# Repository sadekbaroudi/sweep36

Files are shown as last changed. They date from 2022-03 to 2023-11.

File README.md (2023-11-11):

# Name

sweep36

A 36 key version of the sweep, maintaining the original diodeless pcb.

# Variations

## sweeeeep

why the name sweeeeep? because an elite-c is required to support the extra features, and an elite-c has 5 additional pins... so 5 Es for the 5 extra pins. Yes, it's dumb, I know.

### Descripiton

This is a reversible pcb that is wired only, has per key leds (only on one of the two variations), oled, and choc spacing. In order to continue to support a no diode setup, I added support for the elite-c, and this is now required for the build. You can use alternative elite-c compatible controllers.

### Versions and features

There are 6 versions of this pcb, as found in the pcb/wired-rgb directory:
* choc: No hotswap, 36 keys
* choc-rotated-inner-thumb: No hotswap, 36 keys, rotated inner thumb similar to the corne
* choc-hotswap: Hotswap only, 36 keys
* ks27-choc: Support for both choc and gateron ks-27 switches, no hotswap. Note that ks-27 switches use MX keycaps on a low profile switch. Given it's choc spacing, you will likely need to use custom smaller MX keycaps if using these switches
* choc-evq-inside: No hotswap, 34 key, with an evqwgd001 roller encoder on the inside thumb key
* choc-evq-outside: No hotswap, 34 key, with an evqwgd001 roller encoder on the outside thumb key

## swweeep

So, to keep the silliness going, this is has an extra W for the wireless only, and 3 Es for the 3 extra required pins on the nice!nano.

### Description (and story)

This was created after the sweeeeep as a wireless alternative. Given the nice!nano has two less gpio than the elite-c, had to remove the data pin (and therefore TRRS). So, this is wireless only!

Given it's a wireless only build, it made sense to add nice!view support, given it consumes 1000x less power than the typical OLED. That meant that it would consume one too many gpio. In the spirit of low power consumption, removing per key rgb was a natural decision, leaving it with just enough gpio for this board.

So, backstory aside, the net of it is:
* nice!nano required
* nice!view support
* wireless only (no TRRS)
* JST spaced battery through holes
* on/off switch
* both kailh hotswap and mill max compatible through hole

Special thanks to @jasonhazel for kickstarting the initiative!

### Notes

Regarding the JST footprint, you can solder directly or use jst. If soldering, connect power to the middle hole (with the +) and GND to the -. If using JST, be sure to look at your battery wiring and connect the JST connector such that the power lines up with the middle pin (again, with thhe + on the silkscreen)

It is possible to also produce a PCB baseplate board for the swweeep with a nice silkscreen, the kicad files are [here](https://github.com/sadekbaroudi/sweep36/tree/master/sweeeeep), or if you think the [Great Wave Off Kanagawa](https://en.wikipedia.org/wiki/The_Great_Wave_off_Kanagawa) would make a good silkscreen, the gerbers for that are [here](https://github.com/sadekbaroudi/sweep36/blob/master/swweeep/swweeep-base/gerber/v1.0-kanagawa-gerbers.zip)

## dweeeeep

### Description

This was created after both of the other variations. It was created as an alternative to the sweeeeep. It's a sweeeeep with diodes. I know the principle of the original sweep was to have no diodes. I apologize, this was a special request to allow people to use a pro micro compatible controller, as they're much cheaper.

# Support me!

I have spent a lot of time and money designing prototypes, testing, developing, etc. Any contributions would be greatly appreciated!

If you don't want to, or can't afford to support me, please send me a message to let me know you've built one, along with pictures. Also, feel free to submit a pull request with pictures into this repository. I'd be happy to showcase your build.

Reddit: /u/sadekbaroudi
Discord: sadekbaroudi#1258



# Firmware

## Vial (wired version only)

Special thanks to [Jason Hazel](https://github.com/jasonhazel) for adding vial support. Note that given vial with split code takes up most of the space, there is no support for the OLED or per key RGB. If you want those features, please use QMK below.

https://github.com/sadekbaroudi/vial-qmk/tree/vial/keyboards/fingerpunch/sweeeeep

## QMK (wired version only)

https://github.com/sadekbaroudi/qmk_firmware/tree/master/keyboards/fingerpunch/sweeeeep

## ZMK (wireless version only)

https://github.com/sadekbaroudi/zmk-swweeep

# swweeep v1.3 fix

If you built a swweeep v1.3 or earlier, you will need to connect the battery ground pin to the controller gnd pin, as shown below:

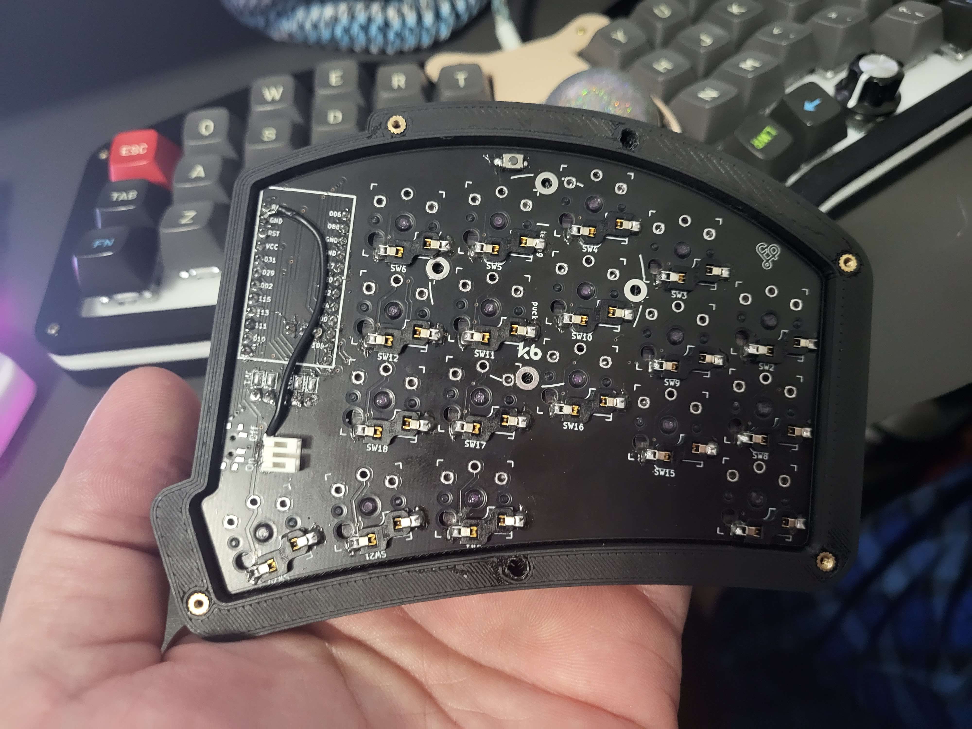
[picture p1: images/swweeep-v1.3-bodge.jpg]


# Pictures

## swweeep with nice!view

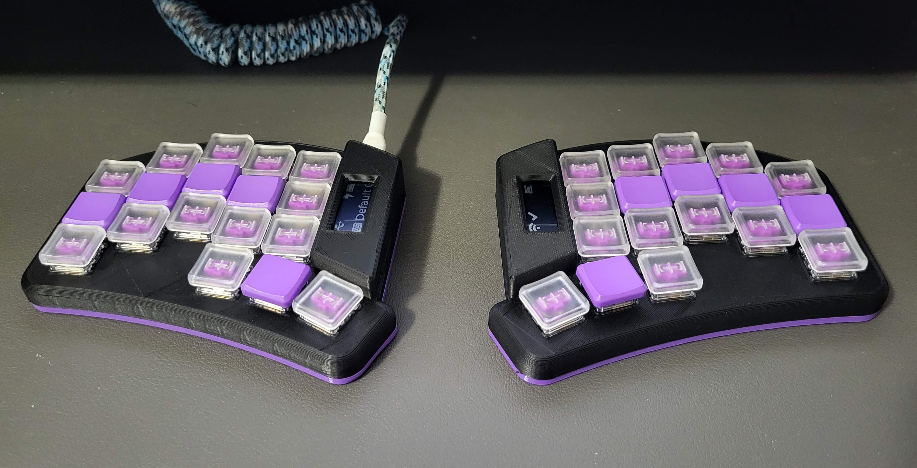
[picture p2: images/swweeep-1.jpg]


## swweeep with the base plate

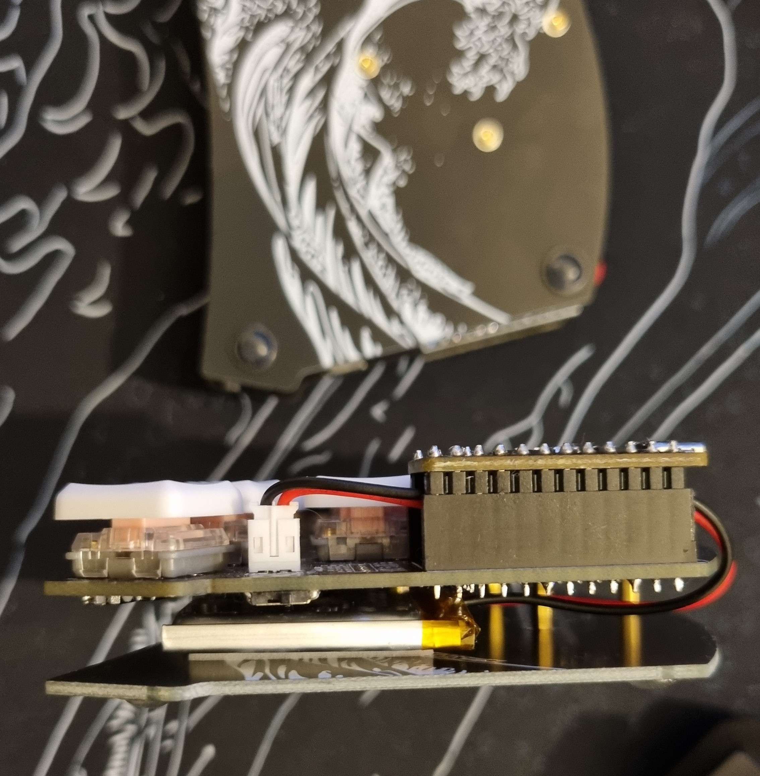
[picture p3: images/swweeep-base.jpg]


## sweeeeep choc

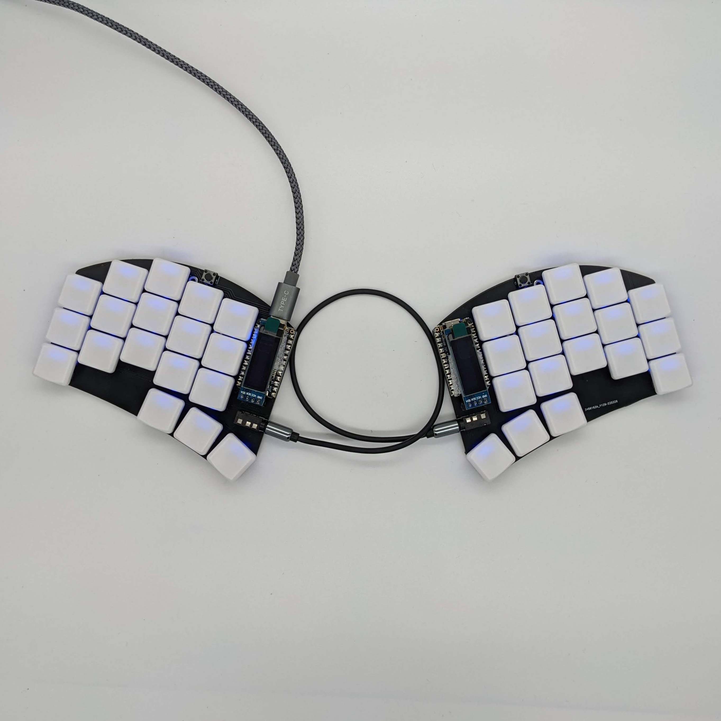
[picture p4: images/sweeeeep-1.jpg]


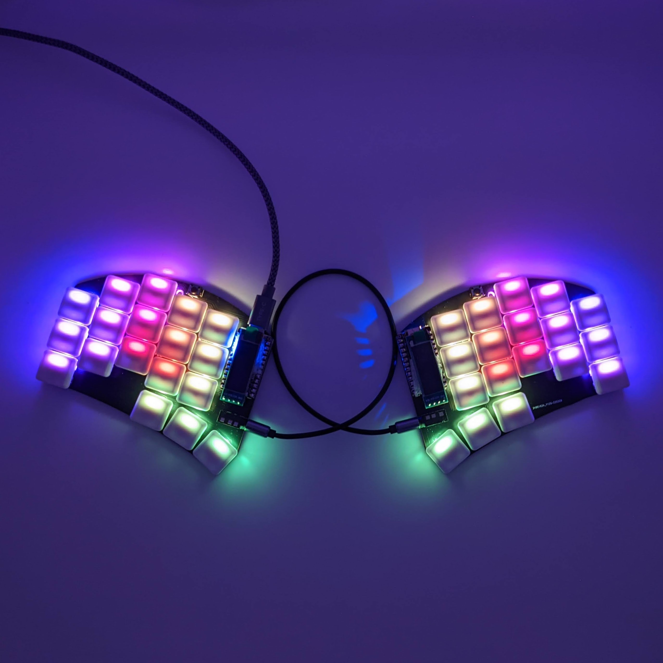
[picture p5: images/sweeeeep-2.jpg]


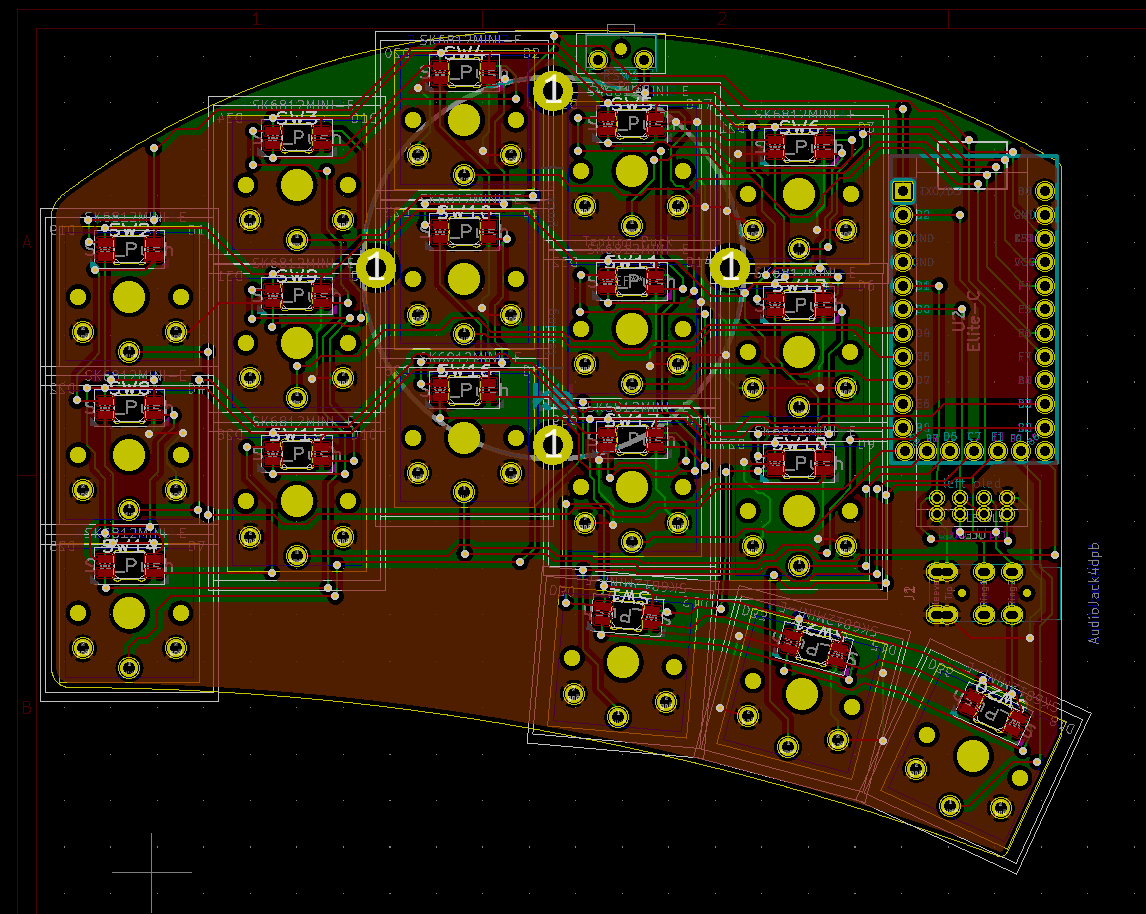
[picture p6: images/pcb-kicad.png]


## sweeeeep evq inside

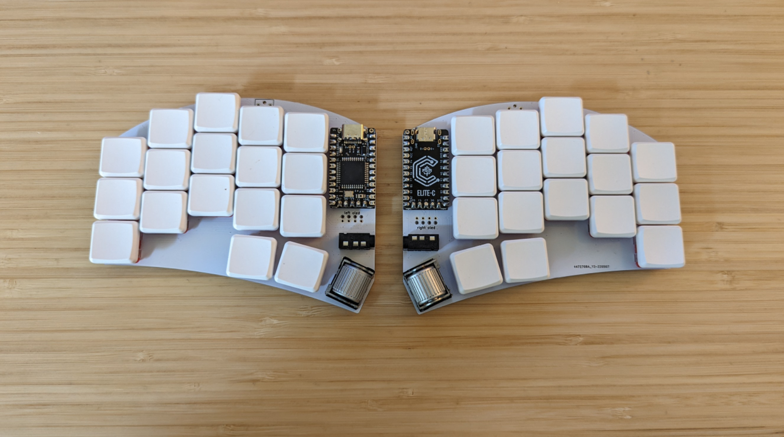
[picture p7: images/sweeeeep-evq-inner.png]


### sweeeeep (choc)
| Front | Back |
| :---: | :---: |
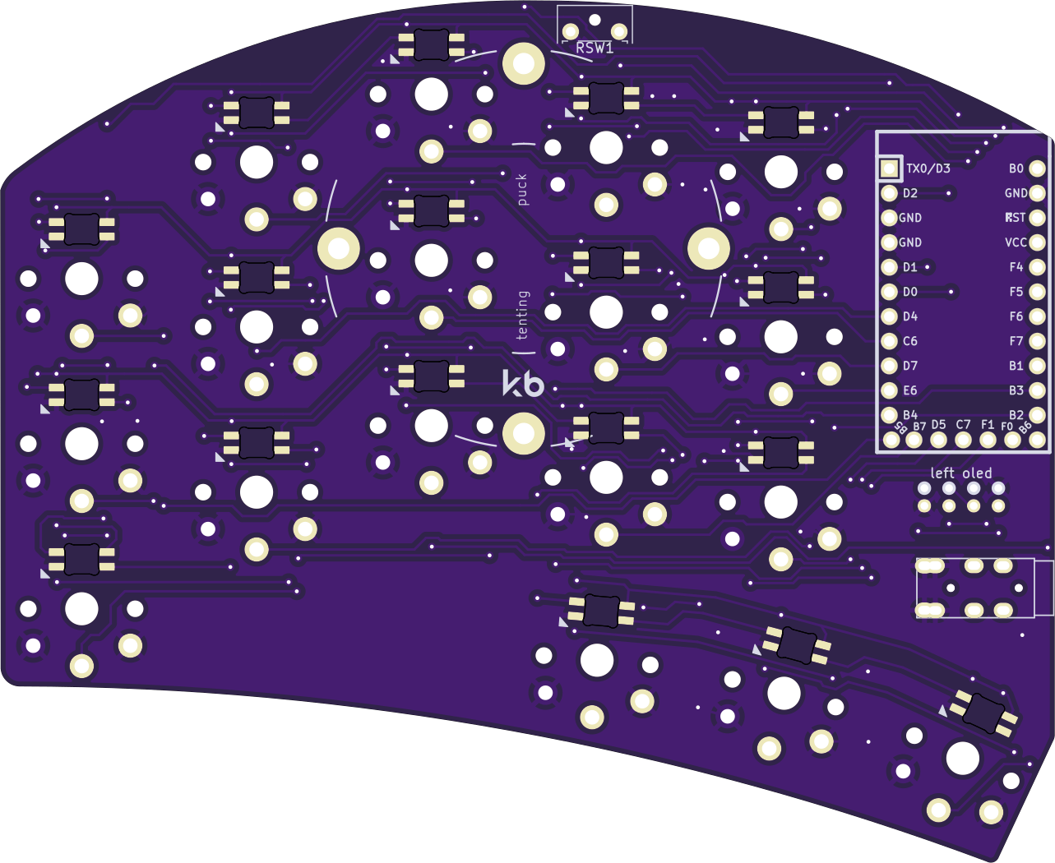
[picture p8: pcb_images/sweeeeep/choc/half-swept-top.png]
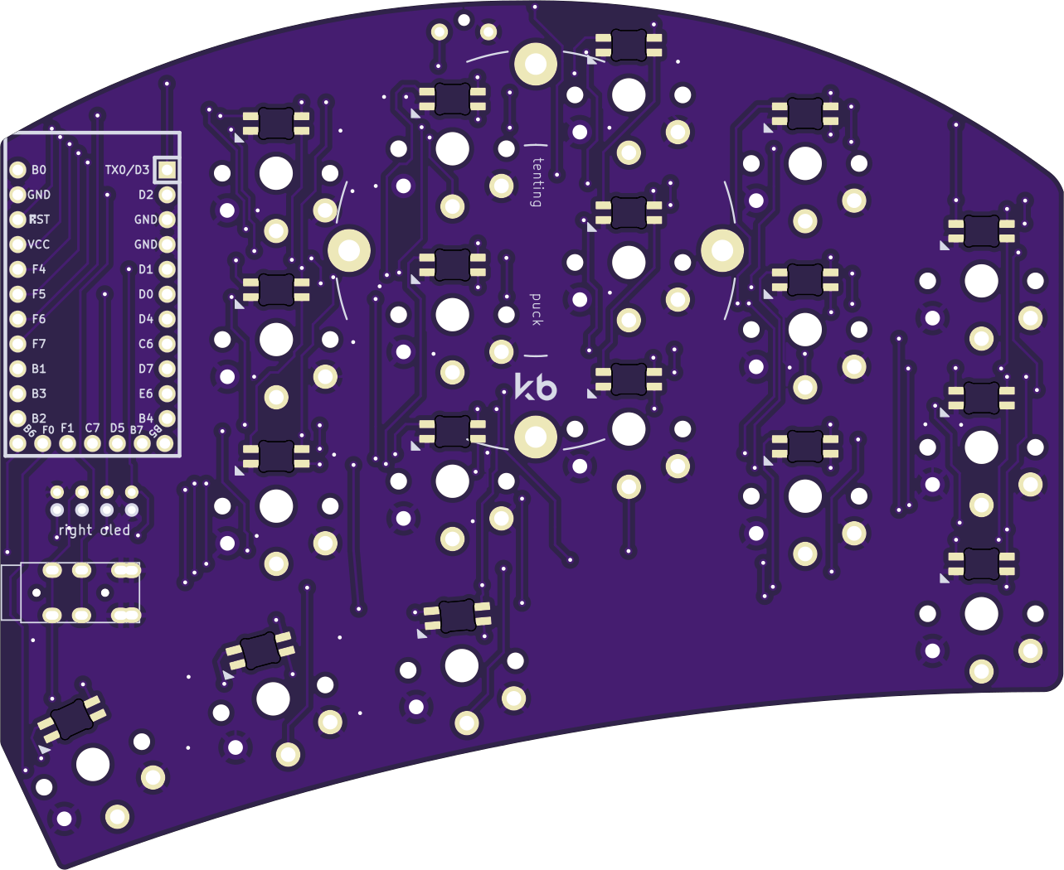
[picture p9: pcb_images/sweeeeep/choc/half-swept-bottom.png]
|  |  |

### sweeeeep (choc-evq-inside)
| Front | Back |
| :---: | :---: |
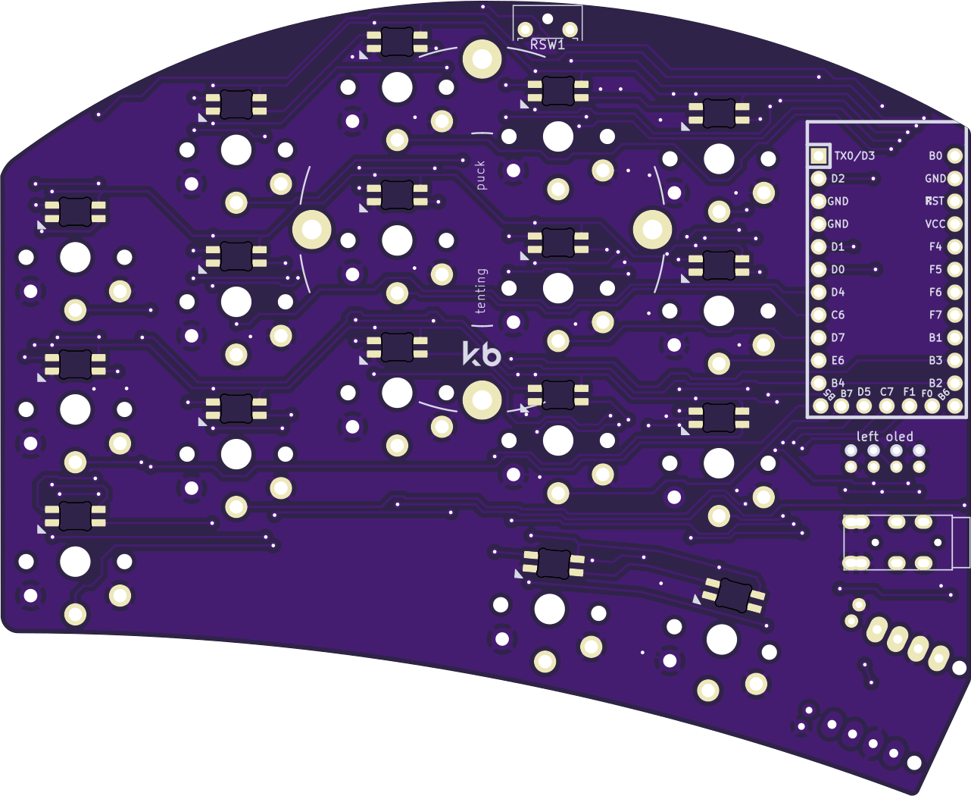
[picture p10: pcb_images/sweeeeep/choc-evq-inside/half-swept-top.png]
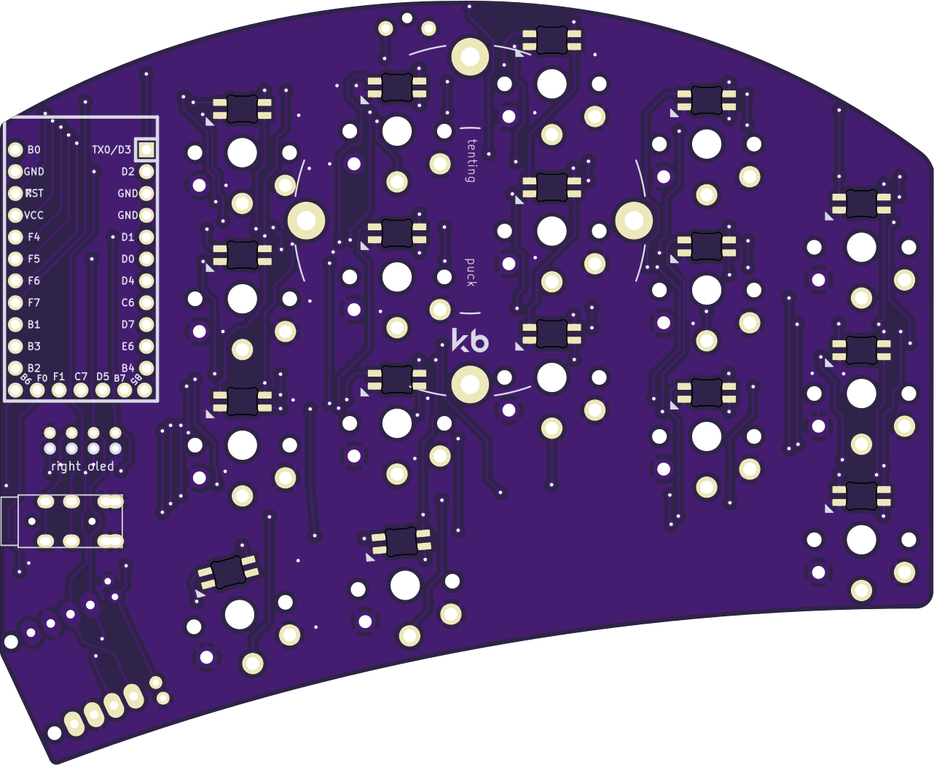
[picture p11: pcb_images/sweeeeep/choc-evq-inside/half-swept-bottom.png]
|  |  |

### sweeeeep (choc-evq-outside)
| Front | Back |
| :---: | :---: |
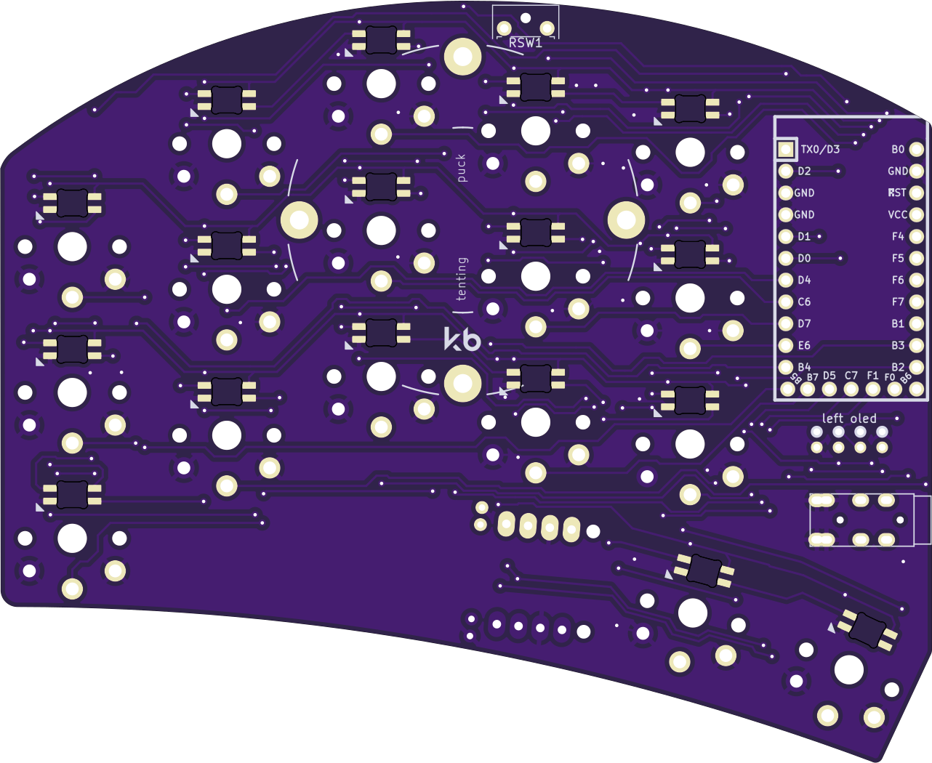
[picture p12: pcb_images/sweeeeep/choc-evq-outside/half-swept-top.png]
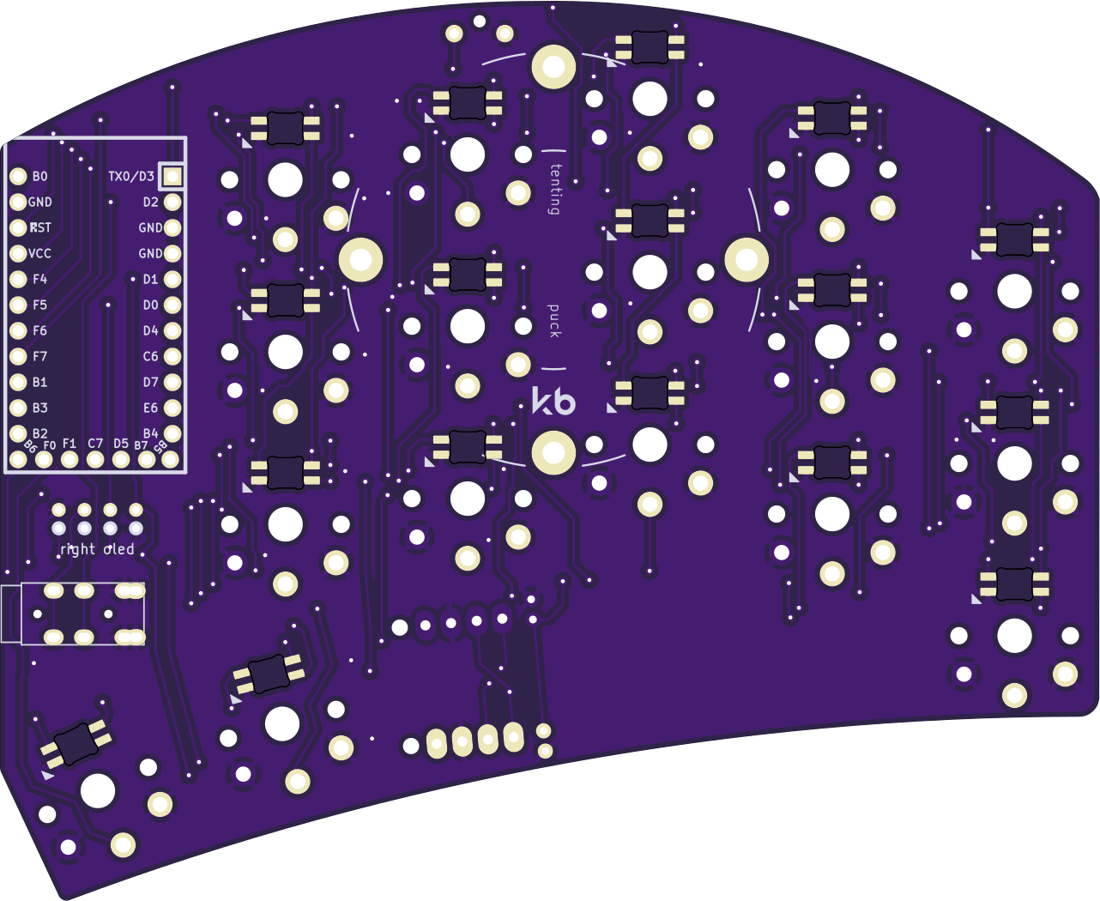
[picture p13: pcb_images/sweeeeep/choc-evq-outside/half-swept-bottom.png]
|  |  |

### sweeeeep (choc-hotswap)
| Front | Back |
| :---: | :---: |
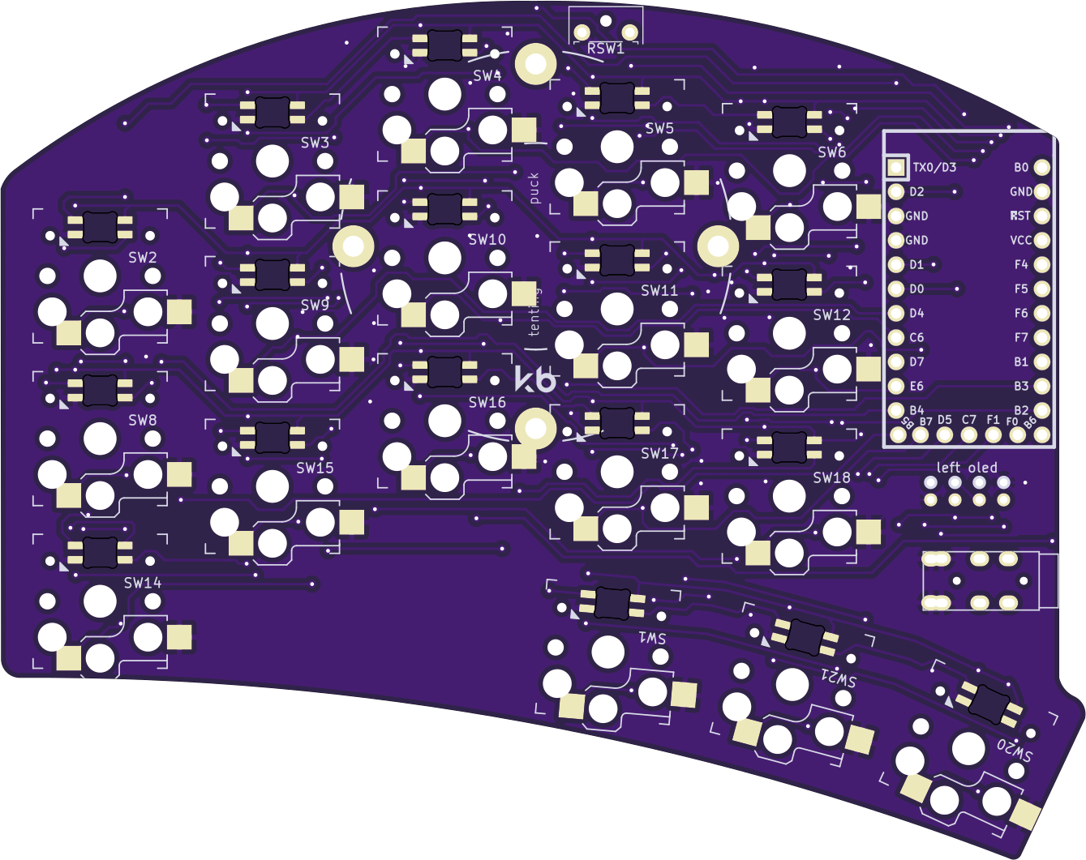
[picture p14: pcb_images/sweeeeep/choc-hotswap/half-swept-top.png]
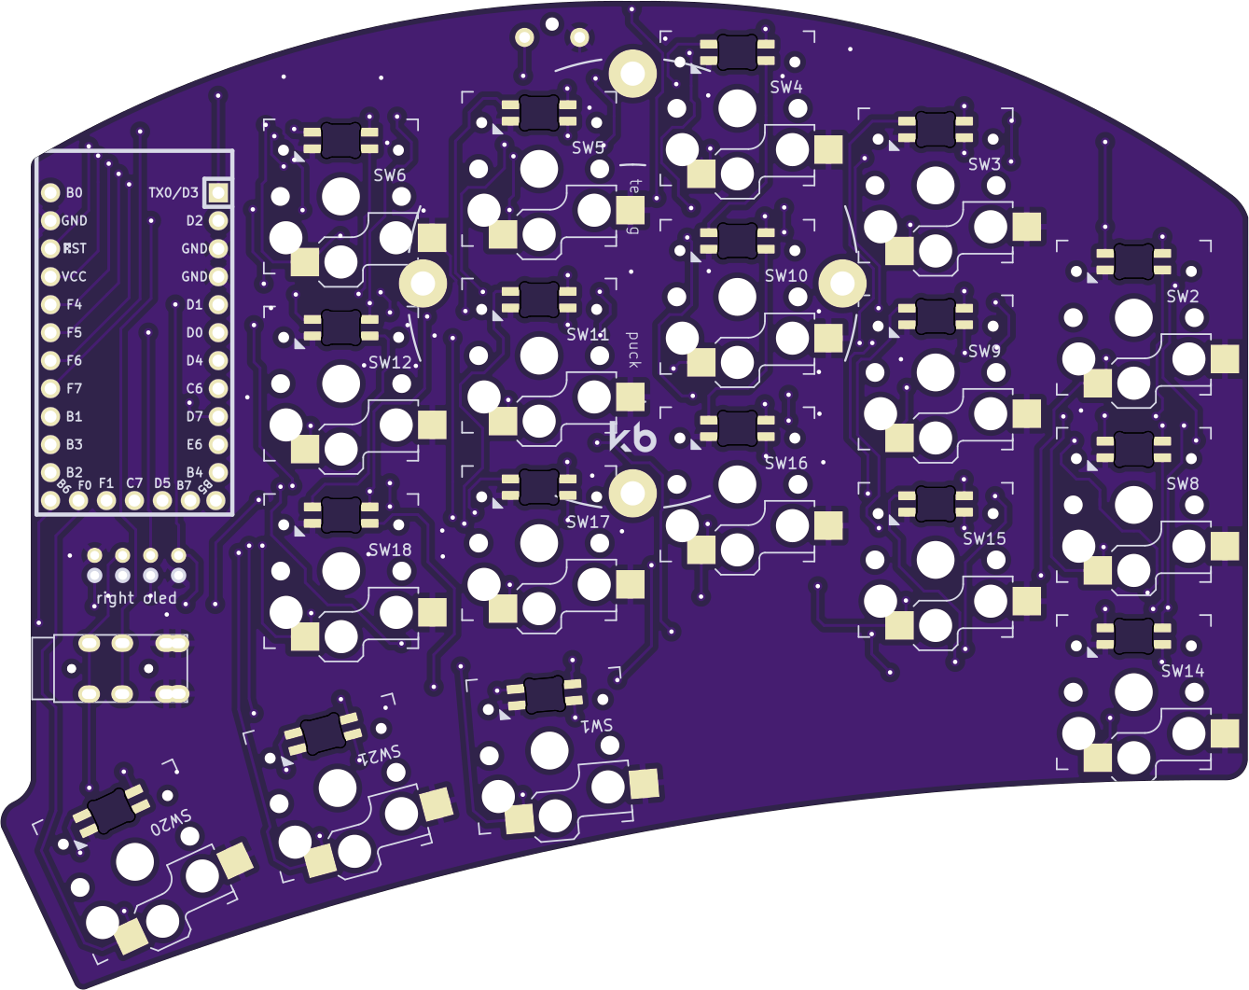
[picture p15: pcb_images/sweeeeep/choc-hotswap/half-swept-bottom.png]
|  |  |

### sweeeeep (choc-rotated-inner-thumb)
| Front | Back |
| :---: | :---: |
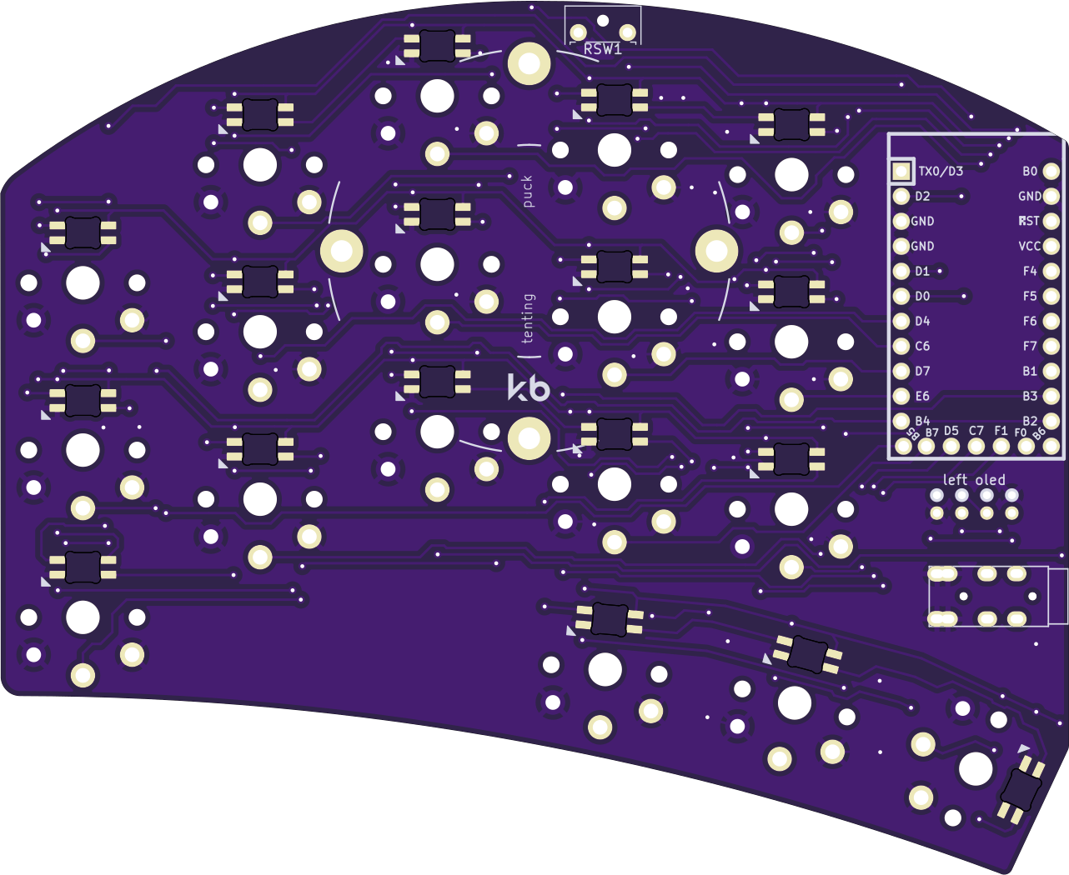
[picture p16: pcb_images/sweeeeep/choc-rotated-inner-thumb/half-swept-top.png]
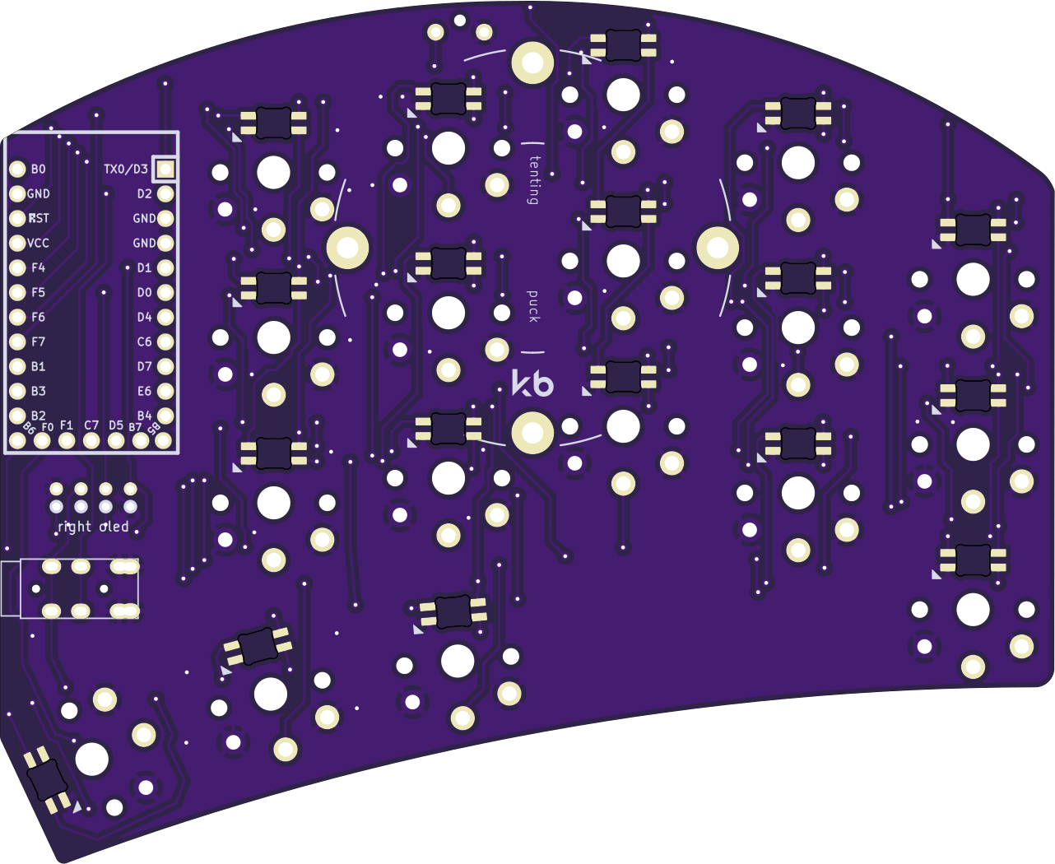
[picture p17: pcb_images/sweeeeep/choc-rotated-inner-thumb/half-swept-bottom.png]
|  |  |

### sweeeeep (ks27-choc)
| Front | Back |
| :---: | :---: |
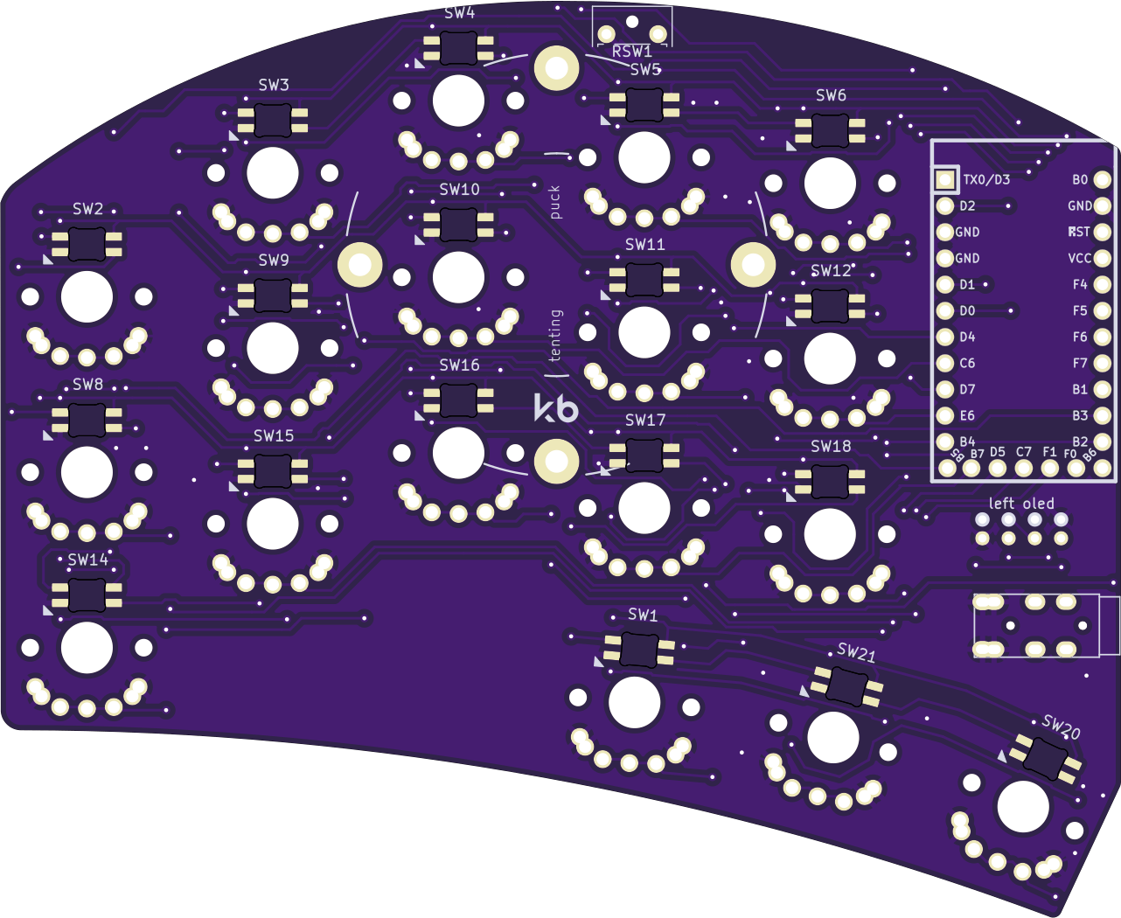
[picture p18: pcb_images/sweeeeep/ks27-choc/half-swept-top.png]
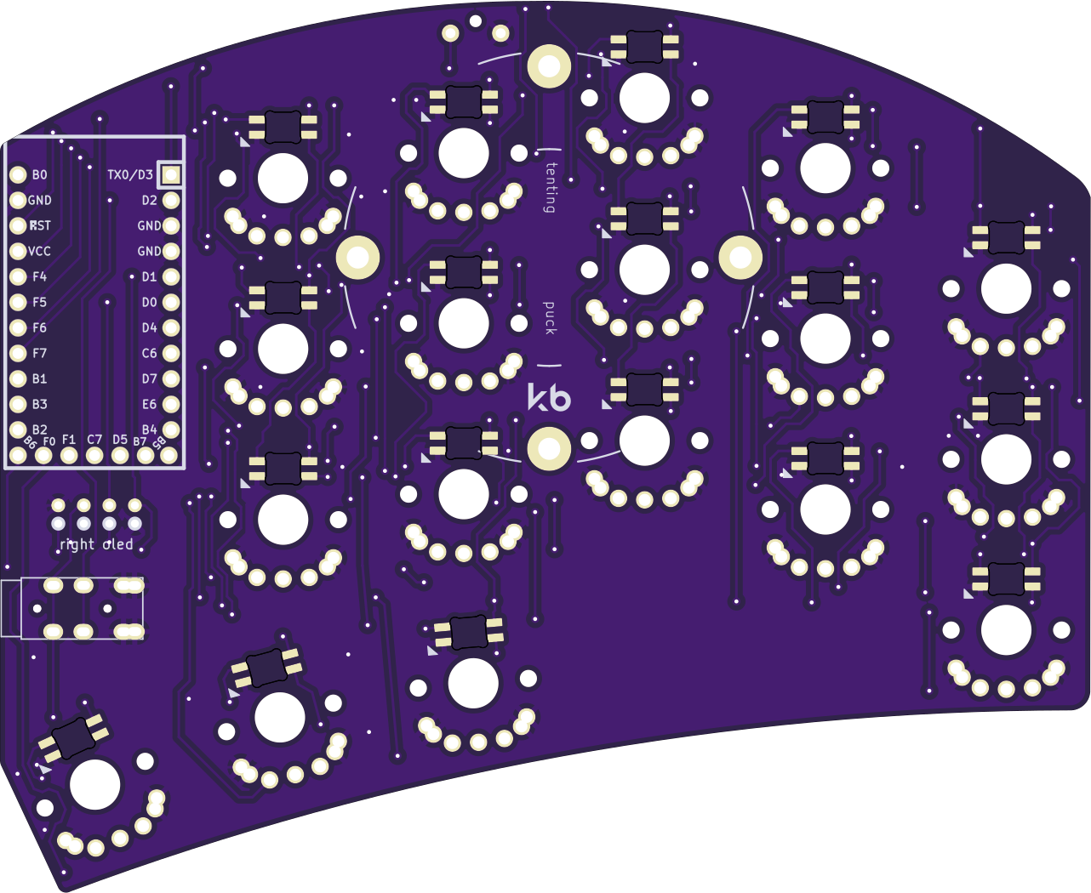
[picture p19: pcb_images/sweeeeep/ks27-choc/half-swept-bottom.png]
|  |  |

### swweeep (choc-hotswap-optional)
| Front | Back |
| :---: | :---: |
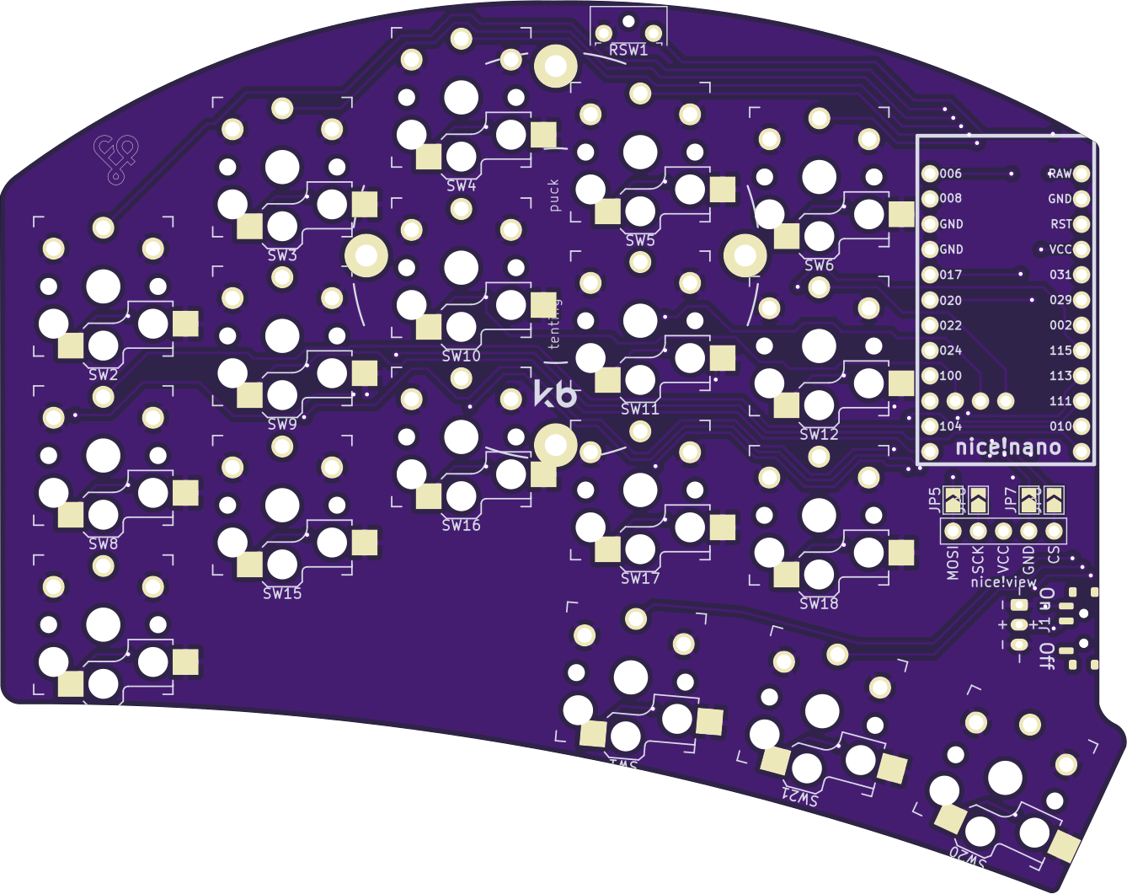
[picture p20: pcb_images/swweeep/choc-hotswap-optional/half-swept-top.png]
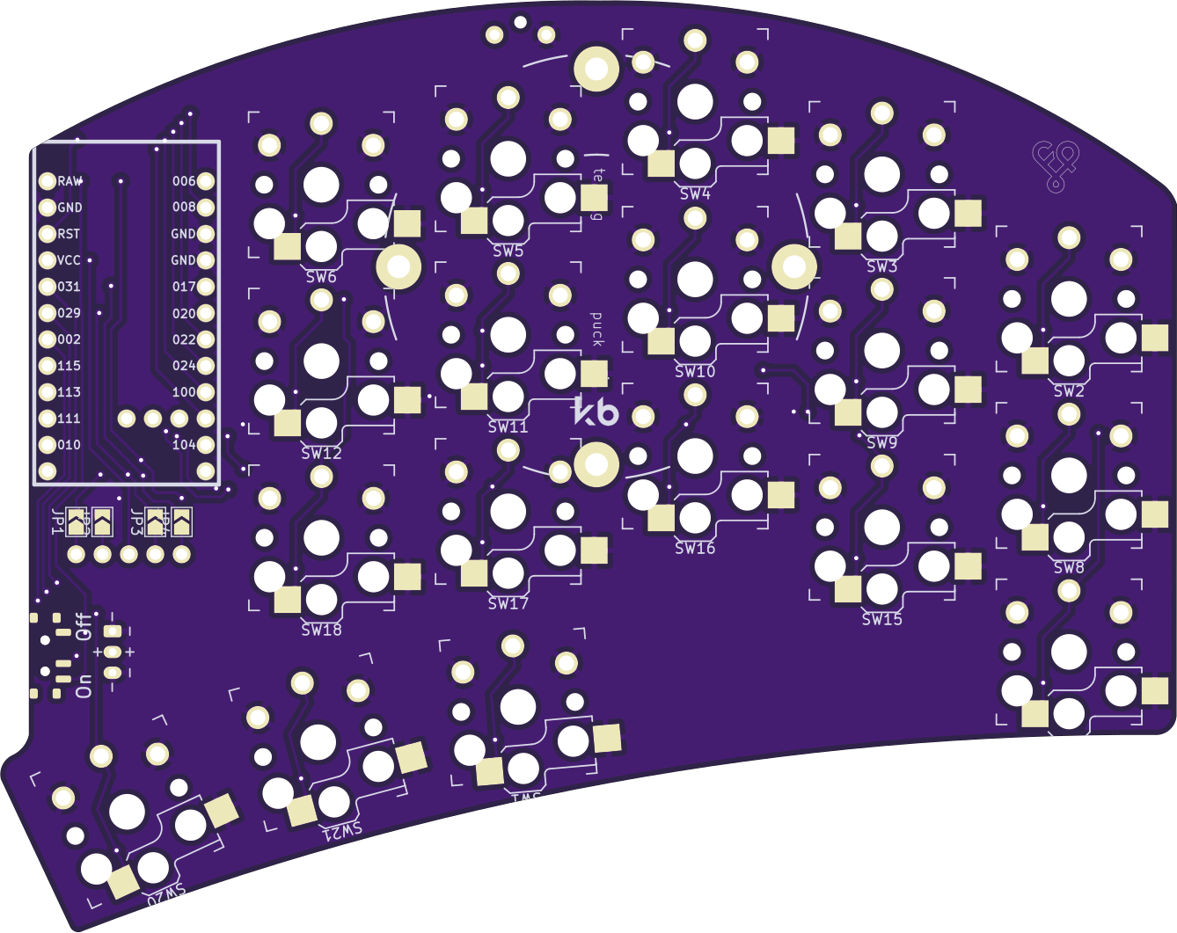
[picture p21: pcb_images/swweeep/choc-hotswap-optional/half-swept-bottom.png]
|  |  |

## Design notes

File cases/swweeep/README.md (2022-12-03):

# swweeep case

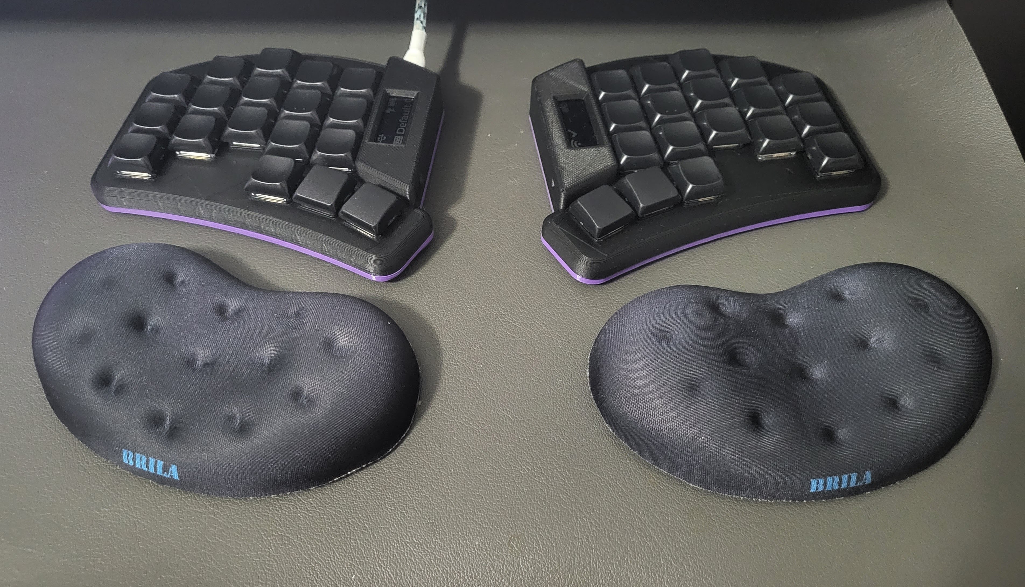
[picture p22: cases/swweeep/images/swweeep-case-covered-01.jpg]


## Required parts

* 2x body
* 2x bottom plate
* On off switch extension (optional)
* 8-12x M2 heat set inserts, 4mm in length
* 8-12x M2 screws, 4-6mm in length (5mm is best)

`swweeep-on-off-extension-small`, `swweeep-on-off-extension-medium`, and `swweeep-on-off-extension-large`

## Bodies

### swweeep-body-open-left

This is an uncovered case, which means the controller is exposed. Not recommended if using the nice!view, but fine otherwise

### swweeep-body-covered-left

Covered controller, to be used with a nice!view

### swweeep-body-covered-widecover-left

Covered controller, to be used with nice!view. This provides enough room on the side of the controller to store a 110 mah battery. Note that this leaves the on/off switch a bit from from the opening on the inside, so you'll need more precision with tweezers or a paper clip to turn it on and off.

However, given you can store the battery on top, you can use the thin bottom bottom plate with this ( `swweeep-bot-widecover-left` )

## Bottom Plates

### swweeep-bot-left

This is a thin bottom plate, intended to be used with `swweeep-body-covered-left` or `swweeep-body-open-left`. Only use this plate if you have a 3mm thick battery and you are not using a JST connector. Otherwise, please use the `swweeep-bot-3mm-left` plate.

### swweeep-bot-3mm-left

This is a thin bottom plate, intended to be used with `swweeep-body-covered-left` or `swweeep-body-open-left`. As mentioned above, made to give a little extra room for a 4mm-4.5mm thick battery and/or a JST connector.

### swweeep-bot-widecover-left

This is a thin bottom plate, intended to be used with `swweeep-body-covered-widecover-left`. Given you are using this case to store the battery on the side of the controller, this is the recommended bottom plate.

### swweeep-bot-widecover-3mm-left

This is a thin bottom plate, intended to be used with `swweeep-body-covered-widecover-left`. I added this for good consistency, but it's unlikely you'd use this one. The only reason to use this bottom plate is that you are using the `swweeep-body-covered-widecover-left` body, not putting the battery next to the controller, and you have a 4mm thick battery or are using a JST connector.

### swweeep-bot-10deg-battery-small

This is a 10 degree tented bottom plate, intended to be used with `swweeep-body-covered-left` or `swweeep-body-open-left`. There is a small battery compartment in the tent to put your battery. Fits a 4mm thick 110 mah battery, up to 12mm x 33mm. Note that if you are using a JST connector, you should use the `swweeep-bot-10deg-battery-large` bottom plate. The positioning of the hole for this one is a bit off to the left, and the JST requires more space between the PCB and the plate.

### swweeep-bot-10deg-battery-large

This is a 10 degree tented bottom plate, intended to be used with `swweeep-body-covered-left` or `swweeep-body-open-left`. There is a large battery compartment in the tent to put your battery. Fits a battery up to 30mm x 52mm x 8mm

### swweeep-bot-18deg-18650

This is a 18 degree tented bottom plate, intended to be used with `swweeep-body-covered-left` or `swweeep-body-open-left`. Run the wires through the small holes in the bottom plate and solder to the pcb. Make sure the wires are long enough that you can safely take off the bottom plate without ripping the wires out of the through holes.

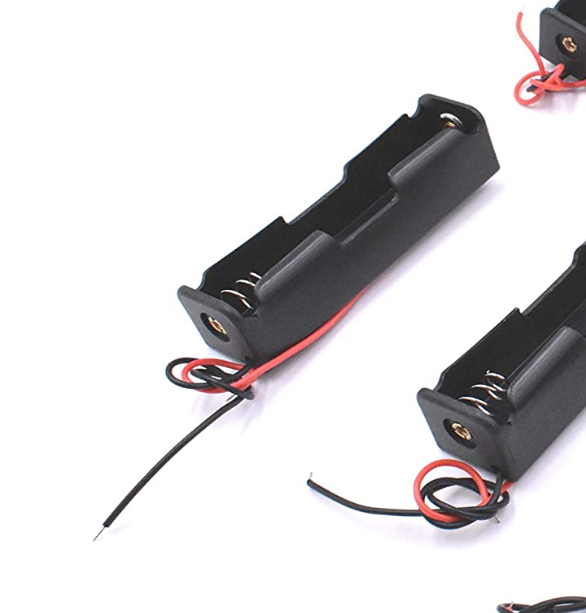
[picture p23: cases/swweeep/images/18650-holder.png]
18650-holder


## On Off Switch Extension

NOTE: This is only intended to be used with swweeep-v1.4 or prior, as I have changed the on/off switch. If you prefer the smaller switch with this switch extension, please feel free to fab v1.4. If you want the larger on/off switch, use v1.5. Please see the releases tab in the github repo to select which you want to use.

This is a cover for the on off switch. It should be placed into the hole for the on off switch before putting the pcb into the case. There are three versions of this, since different printers can generate slightly different results, especially at this scale. Please experiment with all of them until you find one that works.

(Special thanks to @kyek for the idea to do this)

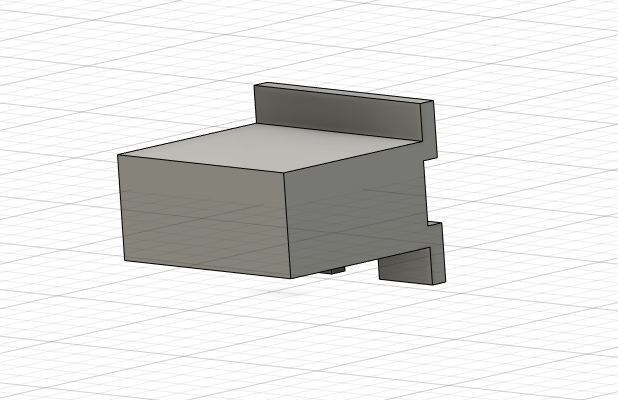
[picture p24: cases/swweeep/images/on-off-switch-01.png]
on-off-switch-01

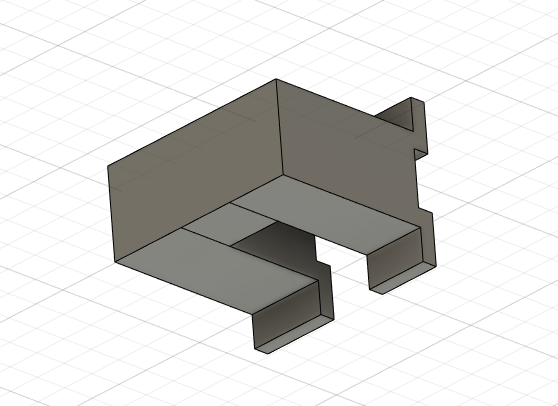
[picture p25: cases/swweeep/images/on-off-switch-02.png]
on-off-switch-02

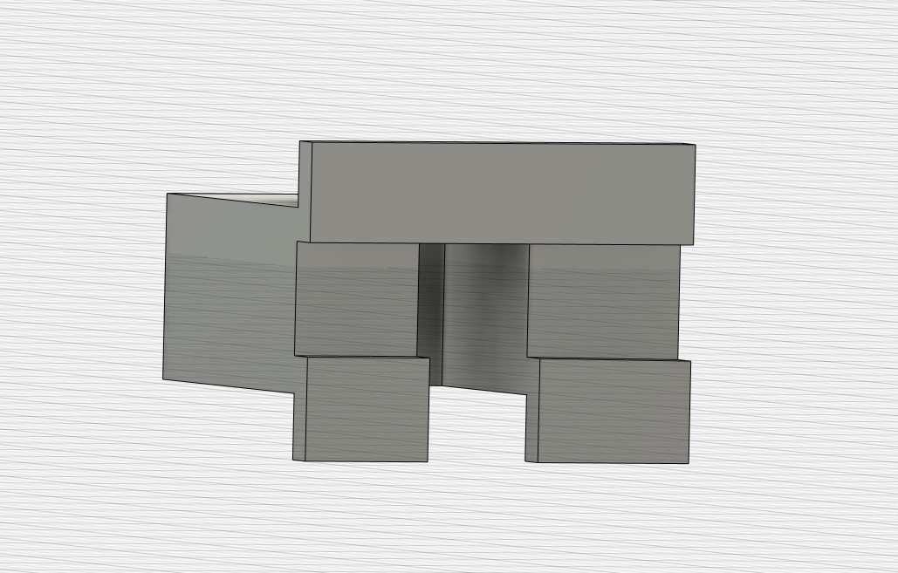
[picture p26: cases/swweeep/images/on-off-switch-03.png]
on-off-switch-03

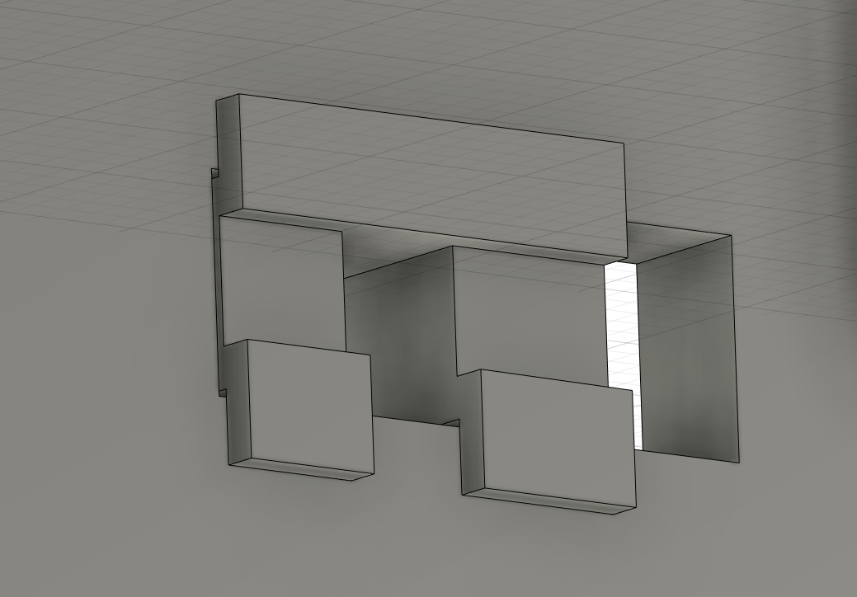
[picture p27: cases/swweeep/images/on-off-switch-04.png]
on-off-switch-04

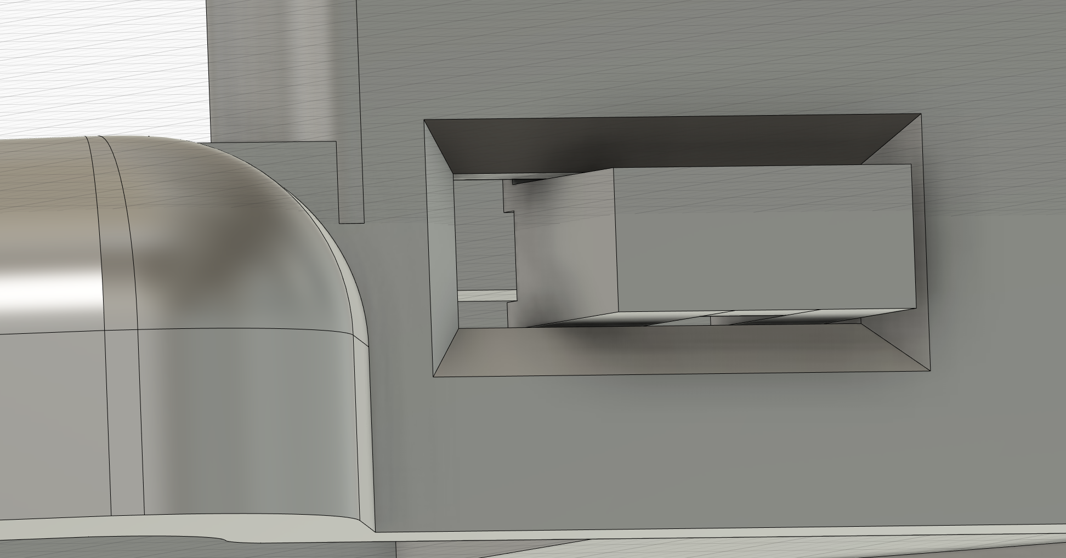
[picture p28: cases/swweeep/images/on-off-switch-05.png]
on-off-switch-05


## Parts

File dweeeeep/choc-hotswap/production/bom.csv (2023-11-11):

Designator | Footprint | Quantity | Value | LCSC Part #
D1, D10, D11, D12, D13, D14, D15, D16, D17, D18, D19, D2, D20, D21, D22, D23, D24, D25, D26, D27, D28, D29, D3, D30, D31, D32, D33, D34, D35, D36, D4, D5, D6, D7, D8, D9 | MX_SK6812MINI-E_REV | 36 | SK6812MINI-E
D37, D38, D39, D40, D41, D42, D43, D44, D45, D46, D47, D48, D49, D50, D51, D52, D53, D54, D55, D56, D57, D58, D59, D60, D61, D62, D63, D64, D65, D66, D67, D68, D69, D70, D71, D72 | D_SOD-123 | 36 | 1N4148W | C727110
J1, J2 | TRRS-PJ-320A | 2 | AudioJack4dpb
OL1, OL2 | OLED_v2 | 2 | OLED
RSW1 | SW_Tactile_SPST_Angled_MJTP1117-no-mount | 1 | SW_Push
SW1, SW10, SW11, SW12, SW14, SW15, SW16, SW17, SW18, SW2, SW20, SW21, SW3, SW4, SW5, SW6, SW8, SW9 | Kailh_socket_PG1350_reversible | 18 | SW_Push
U2 | Elite-C | 1 | Elite-C

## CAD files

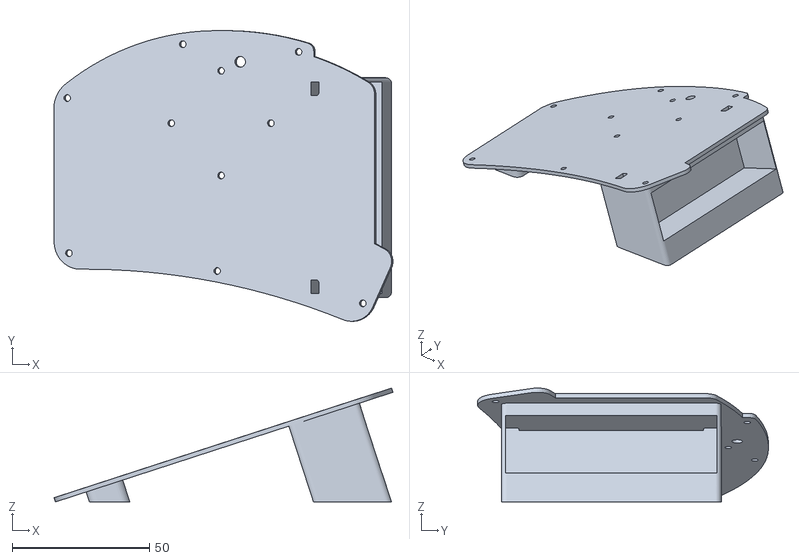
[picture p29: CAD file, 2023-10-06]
cases/swweeep/swweeep-bot-18deg-with-tenting-puck-18650.stl
123.3 x 105.7 x 41.4

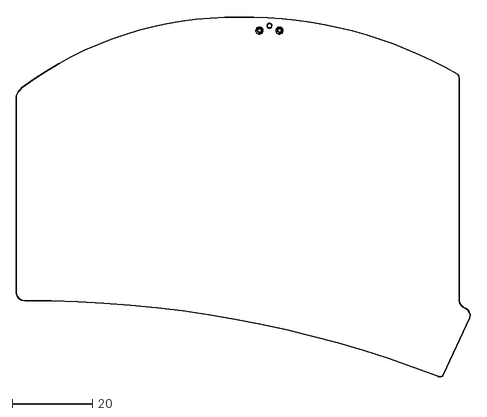
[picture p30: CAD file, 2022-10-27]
swweeep/choc-hotswap-optional/svgs/reset-switch.dxf
113.5 x 90.1

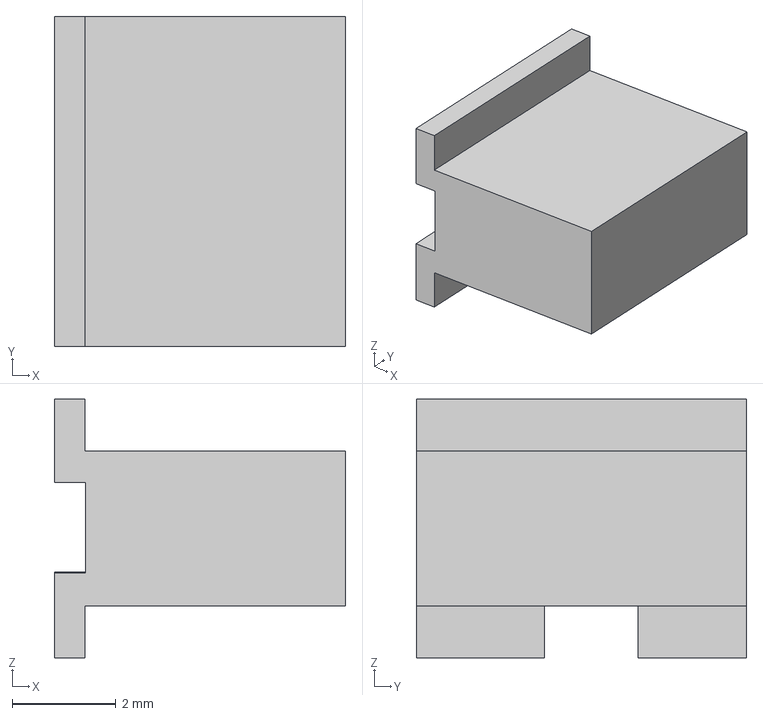
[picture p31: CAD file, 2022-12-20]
cases/swweeep/swweeep-on-off-extension.step
5.60 x 6.36 x 4.98 mm

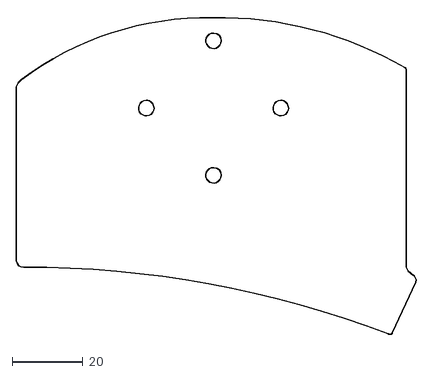
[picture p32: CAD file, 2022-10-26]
swweeep/choc-hotswap-optional/svgs/tenting-puck-placement.dxf
113.5 x 90.1

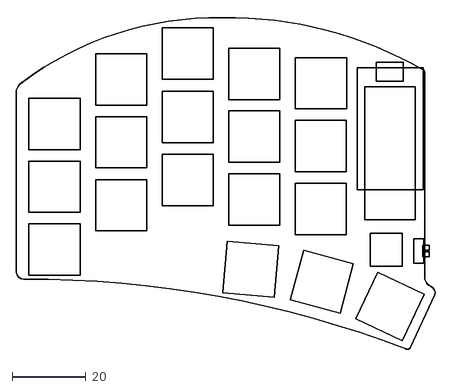
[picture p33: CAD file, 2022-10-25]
swweeep/choc-hotswap-optional/svgs/half-swept-brd.dxf
113.5 x 90.1

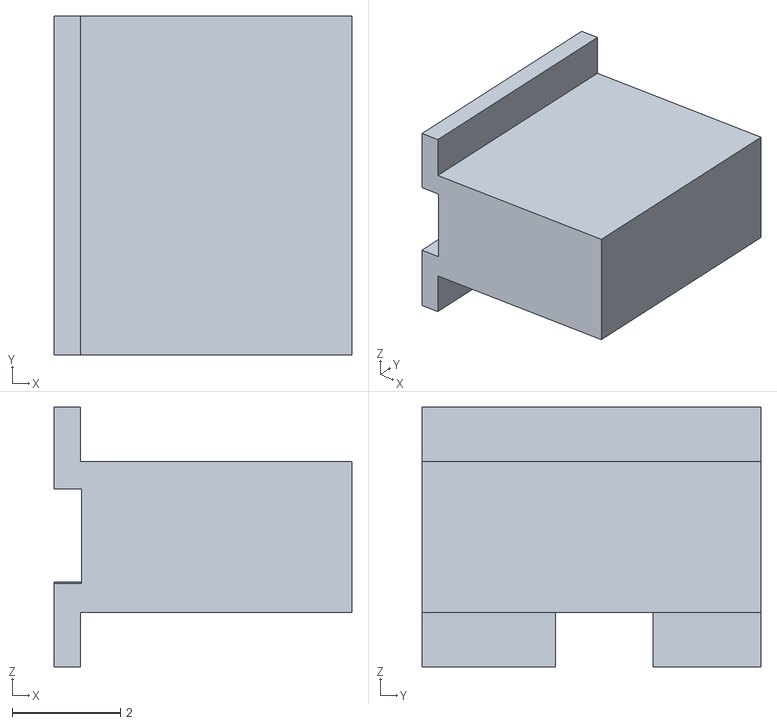
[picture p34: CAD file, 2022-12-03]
cases/swweeep/swweeep-on-off-extension-medium.stl
5.50 x 6.27 x 4.80

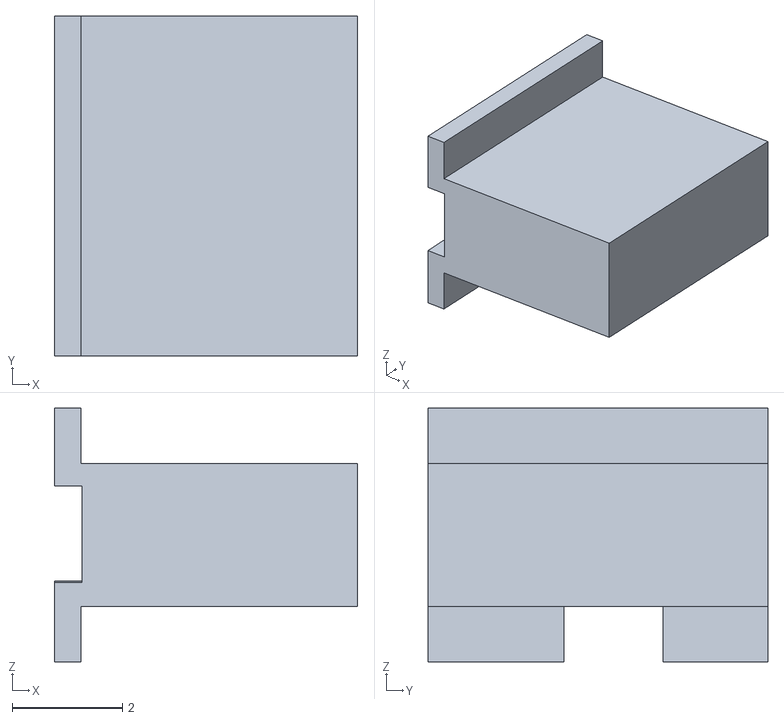
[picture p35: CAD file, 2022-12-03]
cases/swweeep/swweeep-on-off-extension-small.stl
5.50 x 6.17 x 4.60

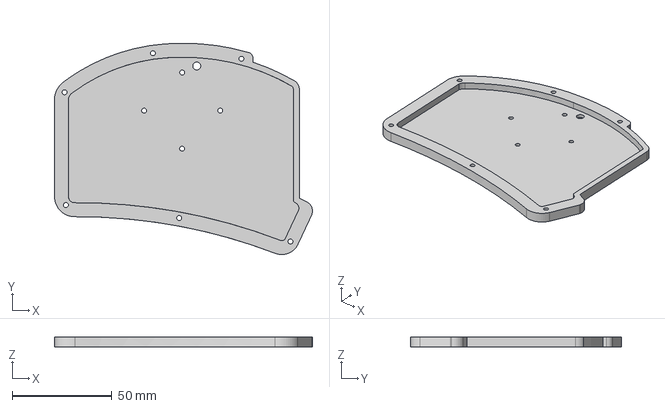
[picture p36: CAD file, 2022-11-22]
cases/swweeep/swweeep-bot-5mm-left.step
129.1 x 105.7 x 5.00 mm

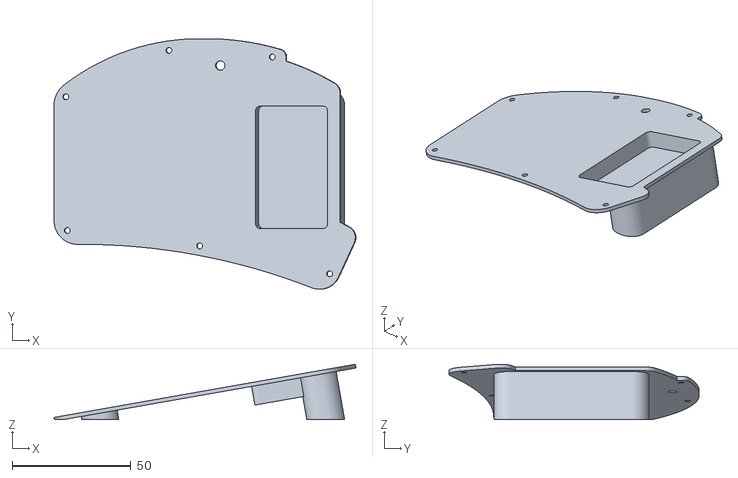
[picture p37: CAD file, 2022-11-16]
cases/swweeep/swweeep-bot-10deg-battery-large.stl
127.4 x 105.7 x 23.4

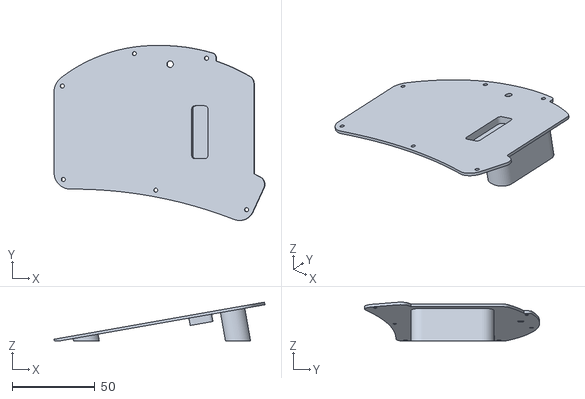
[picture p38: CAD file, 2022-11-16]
cases/swweeep/swweeep-bot-10deg-battery-small.stl
127.4 x 105.7 x 23.4

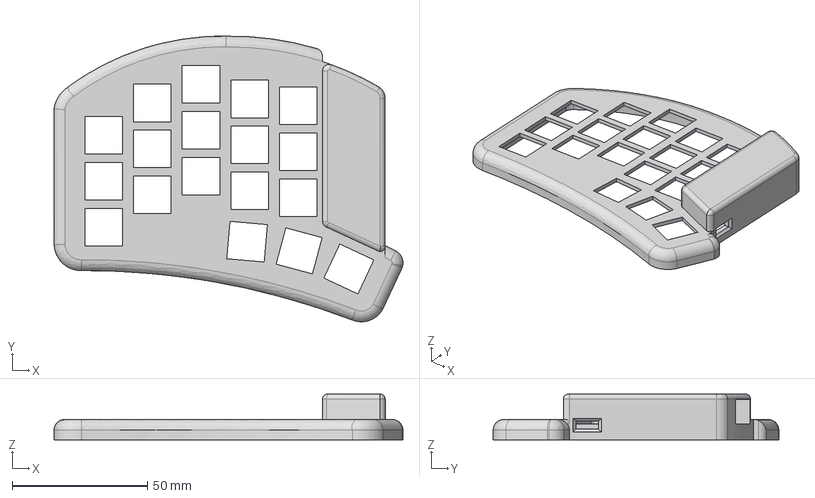
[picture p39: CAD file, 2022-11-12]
cases/swweeep/swweeep-body-covered-noNiceView-left v1.step
129.1 x 105.7 x 17.0 mm

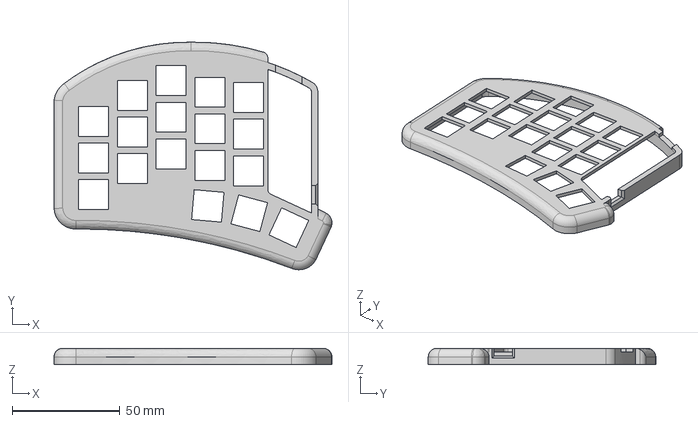
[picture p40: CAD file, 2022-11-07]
cases/swweeep/swweeep-body-open-left.step
129.1 x 105.7 x 7.60 mm

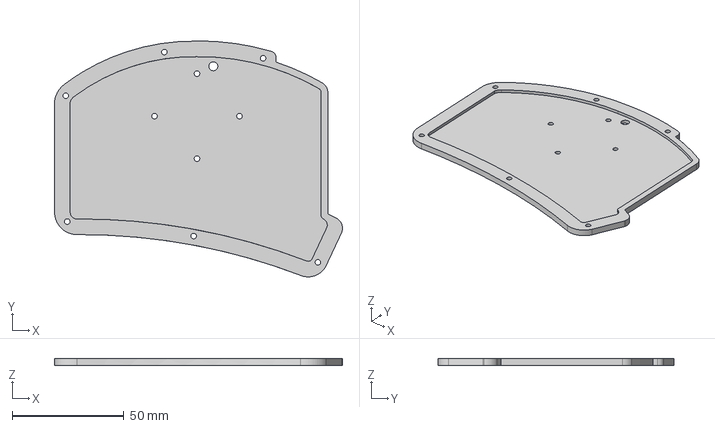
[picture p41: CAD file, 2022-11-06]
cases/swweeep/swweeep-bot-3mm-left.step
129.1 x 105.7 x 3.00 mm

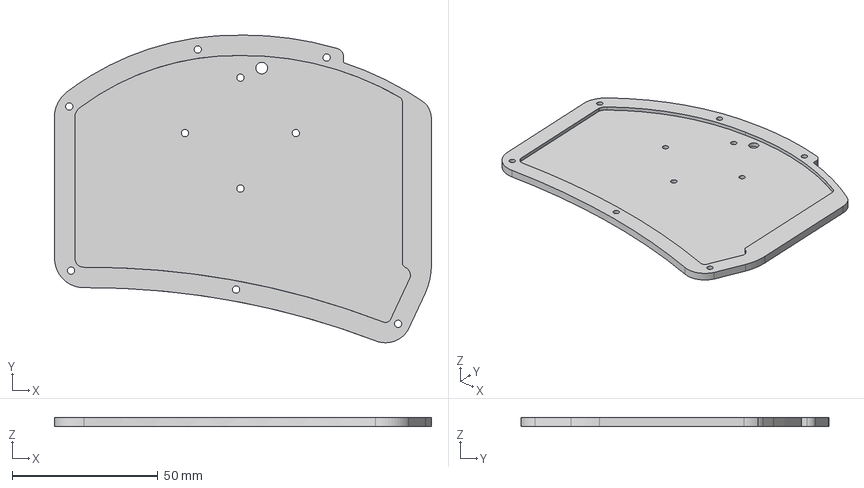
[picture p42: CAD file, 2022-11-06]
cases/swweeep/swweeep-bot-widecover-3mm-left.step
129.6 x 105.7 x 3.00 mm

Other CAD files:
cases/swweeep/swweeep-on-off-extension-large.stl
cases/swweeep/swweeep-bot-18deg-18650.stl
cases/swweeep/swweeep-body-covered-widecover-left.step
cases/swweeep/swweeep-body-covered-left.step
cases/swweeep/swweeep-body-covered-left.stl
cases/swweeep/swweeep-body-covered-noNiceView-left v1.stl
cases/swweeep/swweeep-body-covered-widecover-left.stl
cases/swweeep/swweeep-body-open-left.stl
cases/swweeep/swweeep-bot-3mm-left.stl
cases/swweeep/swweeep-bot-5mm-left.stl
cases/swweeep/swweeep-bot-left.step
cases/swweeep/swweeep-bot-left.stl
cases/swweeep/swweeep-bot-widecover-3mm-left.stl
cases/swweeep/swweeep-bot-widecover-left.step
cases/swweeep/swweeep-bot-widecover-left.stl

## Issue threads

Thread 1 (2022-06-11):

Questions

MisanthropicBit, 2022-06-11:
Thanks for making this keyboard. It is exactly what I've been looking for since I'm already a fan of the ferris sweep (and built one) but wanted 36 keys instead 🙂 This would be my second build though so I'm not terribly experienced and have some questions:

1. What kind of choc semi-transparent keycaps did you use in the pictures? I haven't been able to find something similar in Europe.
2. Can I reuse the same PCB order settings as used in [this Sweep build guide](https://youtu.be/fBPu7AyDtkM?t=21)?
3. What type of hotswaps does the choc-hotswap support? Only [kailh](https://splitkb.com/collections/keyboard-parts/products/kailh-hotswap-sockets), [mill max](https://splitkb.com/collections/keyboard-parts/products/mill-max-hot-swap-sockets), or both?
4. Which LEDs/OLEDs are supported? Can I use these types of [LEDs](https://splitkb.com/collections/keyboard-parts/products/ws2812b-rgb-led?_pos=3&_fid=93ae17f0e&_ss=c) and these [OLED displays](https://splitkb.com/products/oled-display?_pos=1&_sid=3e53e0ada&_ss=r)?

sadekbaroudi, 2022-06-12:
Hi, I'm glad you like it!
1) https://splitkb.com/products/moergo-mcc-profile-1u-keycap
2) Yes!
3) Depends on the version you order... the choc pcb doesn't support hotswap at all. The hotswap version uses kailh
4) You'll need this model of OLED ( https://protosupplies.com/product/oled-0-91-128x32-i2c-white-display/ ) and SK6812 mini-e per key rgb leds

MisanthropicBit, 2022-06-14:
Hey! Thanks for getting back to me.

1. Perfect! Thanks :)
2. Awesome!
3. I plan on ordering the choc-hotswap (if that's what you mean by version) so that should be fine.
4. The OLED screen I linked appears to be the same one, but the LEDs I linked are called SK6812MINI (without the `-e`) so I'm guessing them won't work?

sadekbaroudi, 2022-06-14:
1) No problem! :)
2) N/A
3) Perfect
4) Yeah, they definitely won't work. You need the `-e` as they have a different footprint.

Closed 2022-06-15.

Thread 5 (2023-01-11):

Oled Question

lachlanderrick, 2023-01-11:
Hi mate,

Keyboard looks sweeeeet!

Had a question about oleds. If using [this model](https://protosupplies.com/product/oled-0-91-128x32-i2c-white-display/) that you linked in another isue, are resistors required? I can't see spots for them on the pcb but thought I'd check.

As a related question, what part would you need for socketing the oled? Something like [this](https://kriscables.com/product/oled-hotswap-socket/)? Are there any height requirements for the oled socket?

Cheers!

kriscables, 2023-01-12:
@lachlanderrick from what i checked, i think resistors are not needed, but someone who is more into it could double confirm.

What you linked for socketing Oled is appropriate to use. The height i recommend is the 5mm one, but the 8mm is also possible to use if for some reason you need your oled to stay higher. Also i suggest to use some Dielectric Tape on the pro micro to avoid any shorts between it and Oled.

sadekbaroudi, 2023-01-13:
@lachlanderrick

> Had a question about oleds. If using [this model](https://protosupplies.com/product/oled-0-91-128x32-i2c-white-display/) that you linked in another isue, are resistors required? I can't see spots for them on the pcb but thought I'd check.

No resistors required! I'm not sure what spots on the back you're referring to, but there aren't pads for resistors.

> As a related question, what part would you need for socketing the oled? Something like [this](https://kriscables.com/product/oled-hotswap-socket/)? Are there any height requirements for the oled socket?

Yup! I used something like this as well!

lachlanderrick, 2023-01-13:
Great. One more thing if you don't mind.

Having a bit of trouble tracking down elite-c controllers, especially in my location (Australia). Would the below work? Seems like its a different chip but same form factor I believe. Also has the same number of pinouts compared to the elite-c.

Hopefully you can advise - I appreciate this is a bit of a rogue question.

Thanks again!

https://keebd.com/products/splinky-rp2040-controller-usb-type-c

sadekbaroudi, 2023-01-13:
Yeah, should work! It's a 3.3v controller, so it's a bit low on voltage for per key rgb, but still should work.

You may have some trouble with qmk, since there is no elite-c to splinky converter. You will have to customize the firmware with the RP2040 pinout associated with that controller, most notably for the bottom 5 pins.

Come join the fingerpunch discord server and I can try to help you sort it out when the time comes.

https://fingerpunch.xyz/discord

lachlanderrick, 2023-01-13:
Great! I actually don’t plan to use per key rgb anyway, so that should be fine.

Will definitely jump on the discord. The offer of support is much appreciated.

Closed 2023-01-13.

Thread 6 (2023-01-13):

README says evq variant is hotswap only

pfn, 2023-01-13:
> choc-evq-inside: Hotswap only, 34 key, with an evqwgd001 roller encoder on the inside thumb key
> choc-evq-outside: Hotswap only, 34 key, with an evqwgd001 roller encoder on the outside thumb key

However the PCB images don't show a hotswap footprint nor do the included gerber zips.

sadekbaroudi, 2023-01-14:
Thank you @pfn  ! corrected it in the commit below.

https://github.com/sadekbaroudi/sweep36/commit/f59aeb26bbb336935659e458d003d98ec82a748c

Closed 2023-01-14.

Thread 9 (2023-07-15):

Questions 👋

azzamsa, 2023-07-15:
Hi, Sadek.

> In order to continue to support a no-diode setup, I added support for the elite-c, and this is now required for the build. You can use alternative elite-c compatible controllers.

1) Am I able to use Pro Micro if I don't want to use any LED or display?

2) Is there any reason the `choc-rotated-inner-thumb` doesn't have hot-swap support? Or in other words, why `choc-hotswap:` doesn't have a rotated inner thumb? What is the solution if I want Sweep36 with rotated inner thumb and hot-swap support? Something like `choc-rotated-inner-thumb-hotswap`?

3) Can I use Pro Micro Controller if I don't want to use RGB LED and MCU Display?

Thank you for Sweep36 :heart:

sadekbaroudi, 2023-07-15:
> Am I able to use Pro Micro if I don't want to use any LED or display?

No, the 5 extra pins on the bottom include switches, so the keyboard wouldn't function without an elite-c or equivalent

> Is there any reason the choc-rotated-inner-thumb doesn't have hot-swap support? Or in other words, why choc-hotswap: doesn't have a rotated inner thumb? What is the solution if I want Sweep36 with rotated inner thumb and hot-swap support? Something like choc-rotated-inner-thumb-hotswap?

No particular reason. I just happened to do that one based on the non-hotswap version. If you wanted, you could modify the hotswap version by rotating that thumb key and rewiring it.

> Can I use Pro Micro Controller if I don't want to use RGB LED and MCU Display?

Same answer to the first question. You need an elite-c or equivalent.

sadekbaroudi, 2023-07-15:
> Thank you for Sweep36 ❤️

<3 you're welcome

azzamsa, 2023-07-15:
Thank you for taking time to reply :heart:

Closed 2023-07-15.

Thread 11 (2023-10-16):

Removal of Data Pin - Question about I2C, EVQ roller and more

acvanzant, 2023-10-16:
So I'm here to steal your EVQ roller footprint and symbol, but I'm studying the repo and I noticed that the EVQ roller is wired to the SCL and SDA I2C lines that the OLED uses. That's interesting, I was thinking this was just going to go to 2 GPIO pins, plus a button pin.

It seems someone has made these boards with the rollers, so I assume that works correctly.

My question then becomes, why have another data pin for TRRS? Can't the slave board be a third device on this SDA line?? That frees up that data pin for using the nice!nano or putting extra buttons, without diodes, assuming I'm correct about how I2C could work.

Maybe you'd need a TRRS plug that's 4 pin for the master SCL to move between split boards? I'm sure I'm missing something but I'd sure love to put the EVQ roller on the SCL/SDA i2c bus and also use that bus for master/slave communication, and an OLED, if I could. An extra button or two would be fantastic, using the empty pins on an elite or pi pico even.

How do you set the I2C address on an EVQ roller? I guess that could by why you don't use I2C between boards... The two rollers would have the same address on the SDA line? I wasn't planning on having a roller on both sides, anyway, but that makes sense.

sadekbaroudi, 2023-10-16:
@acvanzant

The SCL / SDA pins don't have to be used for I2C. You can use them as general GPIO, so that's what I did. The reason is that there is not enough GPIO available, so I had to use those.

If I used I2C for split communication, then you're right, I could have freed up the data pin to use for the EVQ, and allowed you to still use the OLED.

The reason I didn't do any of this is because I'd have to have separate firmware for this version versus the rest of the sweeeeeep versions, and I didn't want to maintain that.

If you want to modify it as you specified, you totally can.

acvanzant, 2023-10-16:
ah, yes. sorry. I suppose my 'issue' is that I didn't consider it was either/or. That makes sense. Then this is the minimum pin usage of the scroll wheel and buttons, without an OLED. Sweet thanks.

finelord, 2024-03-02:
I faced this issue building EVQ half with i2c for haptic.

Due to the fact that EVQ is traced to i2c lines, this won't work -- either one or the other.

However, that is not quite true that there's no more free pins, at least for the Elite-C case: there're two unused pins, B0 (aka RAW) and B1. Re-routing EVQ to those allows both i2c devices and EVQ work simultaneously.

For already manufactured PCBs, a bit of trace cutting and couple wires would do the trick.

Other than that, cool Sweep variation, exactly what I was looking for. Thanks!

sadekbaroudi, 2024-03-02:
Hi @finelord !

> However, that is not quite true that there's no more free pins, at least for the Elite-C case: there're two unused pins, B0 (aka RAW) and B1. Re-routing EVQ to those allows both i2c devices and EVQ work simultaneously.

Yes, that's true. The only concern I had with using B0 is that other elite-c footprint controllers may not work, as they don't expose a GPIO on the RAW pin. You're right in that I could done what you described, and then added a constraint that you must use an elite-c specifically.

Thinking about it more, I probably should have put a couple of jumpers near the EVQ that allow you to select either I2C pins OR the Elite-C's B0/B1 pins instead.

Thanks for the feedback, and I hope you enjoy the board!

finelord, 2024-03-03:
The board is awesome, the layout is what I wanted for a while but was too lazy to build myself. I actually mixed EVQ with non-EVQ halves and added haptic for tap-holds. With 25g clicky chocs this is an absolutely amazing build.

Jumper pads would be a nice addition indeed!

sadekbaroudi, 2024-03-03:
> I actually mixed EVQ with non-EVQ halves and added haptic for tap-holds. With 25g clicky chocs this is an absolutely amazing build.

Oooh, that's clever! That does sounds awesome. I don't think many people do stuff like that because it requires a decent understanding of hardware and software. Clearly this ain't your first rodeo :)

Closed 2023-10-16.

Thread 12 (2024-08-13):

Have case files been updated since the switch to OS102011MA1QN1 as the power switch?

lostgent, 2024-08-13:
Just printed a case and the powerswitch hole is too low for the switch. Have I done something wrong?

lostgent, 2024-08-14:
@sadekbaroudi Of course, apologies I should have thought to do that in the first instance - [here](https://imgur.com/a/tCVb5Rs)

sadekbaroudi, 2024-08-14:
@lostgent - thanks for the pics, super helpful! what if you soldered the switch on the bottom side of the pcb instead of the top?

lostgent, 2024-08-15:
@sadekbaroudi - no worries, if you look at the second photo with the side view, you can see that the pcb sits just above the opening, meaning that it's likely the MSK-12C02 switch (on top) would have worked given its low profile.

I'll either try figure out blender to make the hole the right size or figure out a way to cut the ones I've printed already! Just wanted to flag it to you, thanks for creating the Swweeep in the first instance, I'm really looking forward to trying it out!

sadekbaroudi, 2024-08-15:
@lostgent - I still think you just needed to solder the OS102011MA1QN1 on the bottom of the pcb and it would have fit, but maybe I'm missing something

I'm glad you sorted out the case modifications for it, and it will work for you!

Regarding the jumpers, if both halves are face up with the switches on top, solder the bottom side jumpers for each half.

sadekbaroudi, 2024-08-15:
Also, please feel free to close the issue when you feel it's all sorted out!

lostgent, 2024-08-15:
Scholar! Thank you!

Closed 2024-08-15.

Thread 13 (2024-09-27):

Question regarding Elite-C

prabhumarappan, 2024-09-27:
1. In one of the earlier issues you said it is compatible with Elite-C and its alternatives. I looked around but wasn't able to figure out if [this RP2040](https://keeb.io/products/rp2040-pro-micro-usb-c-controller) is compatible? It has 5 bottom pins like the Elite-C too.

sadekbaroudi, 2024-09-27:
@prabhumarappan - absolutely, as long as it is elite-c compatible footprint, it should be fine. You'd just have to use the appropriate QMK converter when compiling.

Closed 2024-09-27.

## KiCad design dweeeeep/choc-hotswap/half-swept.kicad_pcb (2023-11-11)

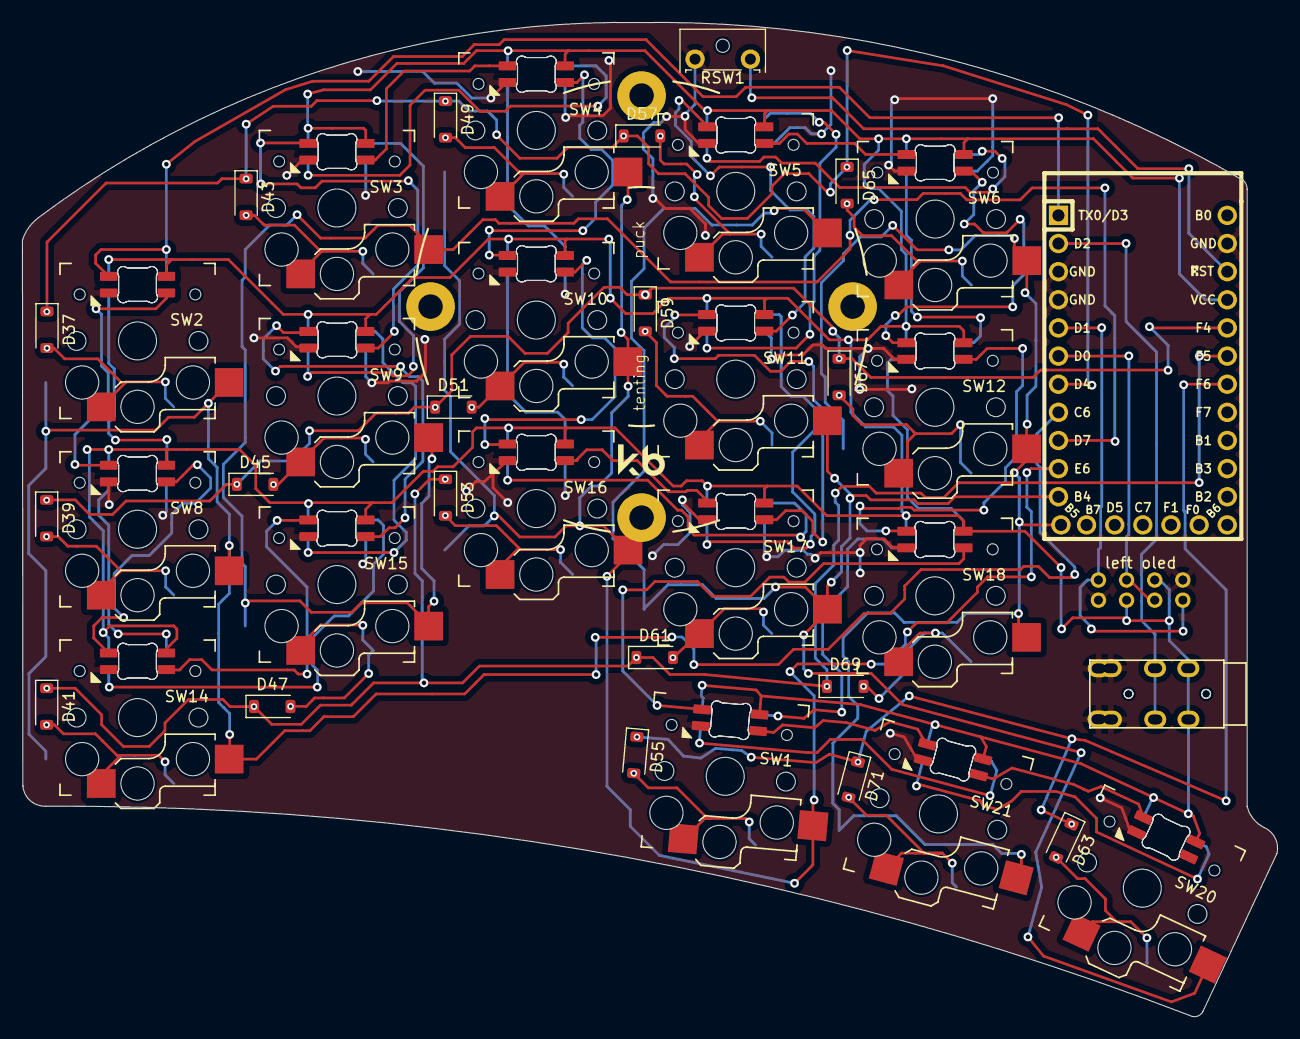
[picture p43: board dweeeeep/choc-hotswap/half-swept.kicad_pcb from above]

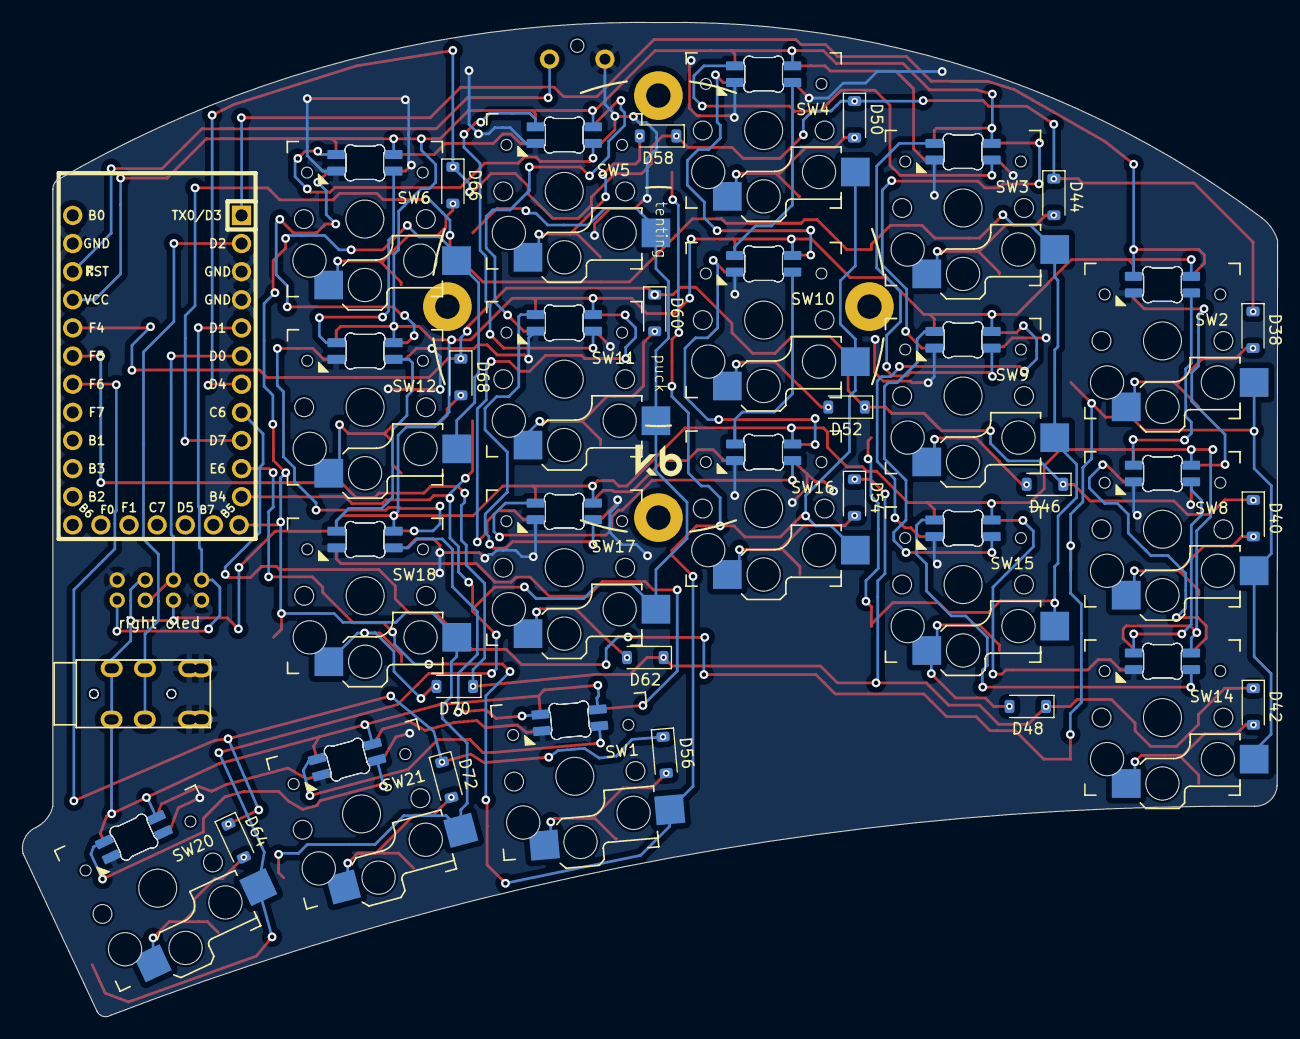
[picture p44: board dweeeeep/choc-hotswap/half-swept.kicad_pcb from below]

Board: 2 copper layers, 113.3 x 89.7 mm, 96 parts (38 on the bottom side), 68 nets.

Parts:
D1, D2, D3, D4, D5, D6, D7, D8, D9, D10, D11, D12, D13, D14, D15, D16, D17, D18, D19, D20, D21, D22, D23, D24, D25, D26, D27, D28, D29, D30, D31, D32, D33, D34, D35, D36: SK6812MINI-E; MX_SK6812MINI-E_REV
D37, D38, D39, D40, D41, D42, D43, D44, D45, D46, D47, D48, D49, D50, D51, D52, D53, D54, D55, D56, D57, D58, D59, D60, D61, D62, D63, D64, D65, D66, D67, D68, D69, D70, D71, D72: 1N4148W; D_SOD-123
J1, J2: AudioJack4dpb; TRRS-PJ-320A
OL1, OL2: OLED; OLED_v2
RSW1: SW_Push; SW_Tactile_SPST_Angled_MJTP1117-no-mount
SW1, SW2, SW3, SW4, SW5, SW6, SW8, SW9, SW10, SW11, SW12, SW14, SW15, SW16, SW17, SW18, SW20, SW21: SW_Push; Kailh_socket_PG1350_reversible
U2: Elite-C

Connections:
unnamed: D1.2 (DOUT), D4.4 (DIN)
unnamed: D2.2 (DOUT), D5.4 (DIN)
unnamed: D3.2 (DOUT), D6.4 (DIN)
unnamed: D4.2 (DOUT), D7.4 (DIN)
unnamed: D5.2 (DOUT), D8.4 (DIN)
unnamed: D6.2 (DOUT), D9.4 (DIN)
unnamed: D7.2 (DOUT), D10.4 (DIN)
unnamed: D10.2 (DOUT), D13.4 (DIN)
unnamed: D8.2 (DOUT), D11.4 (DIN)
unnamed: D11.2 (DOUT), D14.4 (DIN)
unnamed: D9.2 (DOUT), D12.4 (DIN)
unnamed: D12.2 (DOUT), D15.4 (DIN)
unnamed: D13.2 (DOUT), D16.4 (DIN)
unnamed: D14.2 (DOUT), D17.4 (DIN)
unnamed: D15.2 (DOUT), D18.4 (DIN)
unnamed: D2.4 (DIN), D16.2 (DOUT)
unnamed: D3.4 (DIN), D17.2 (DOUT)
unnamed: D19.2 (DOUT), D22.4 (DIN)
unnamed: D20.4 (DIN), D34.2 (DOUT)
unnamed: D20.2 (DOUT), D23.4 (DIN)
unnamed: D21.4 (DIN), D35.2 (DOUT)
unnamed: D21.2 (DOUT), D24.4 (DIN)
unnamed: D22.2 (DOUT), D25.4 (DIN)
unnamed: D23.2 (DOUT), D26.4 (DIN)
unnamed: D24.2 (DOUT), D27.4 (DIN)
unnamed: D25.2 (DOUT), D28.4 (DIN)
unnamed: D26.2 (DOUT), D29.4 (DIN)
unnamed: D27.2 (DOUT), D30.4 (DIN)
unnamed: D28.2 (DOUT), D31.4 (DIN)
unnamed: D29.2 (DOUT), D32.4 (DIN)
unnamed: D30.2 (DOUT), D33.4 (DIN)
unnamed: D31.2 (DOUT), D34.4 (DIN)
unnamed: D32.2 (DOUT), D35.4 (DIN)
unnamed: D33.2 (DOUT), D36.4 (DIN)
unnamed: D37.2 (A), D38.2 (A), SW2.1
unnamed: D39.2 (A), D40.2 (A), SW8.1
unnamed: D41.2 (A), D42.2 (A), SW14.1
unnamed: D43.2 (A), D44.2 (A), SW3.1
unnamed: D45.2 (A), D46.2 (A), SW9.1
unnamed: D47.2 (A), D48.2 (A), SW15.1
unnamed: D49.2 (A), D50.2 (A), SW4.1
unnamed: D51.2 (A), D52.2 (A), SW10.1
unnamed: D53.2 (A), D54.2 (A), SW16.1
unnamed: D55.2 (A), D56.2 (A), SW1.1
unnamed: D57.2 (A), D58.2 (A), SW5.1
unnamed: D59.2 (A), D60.2 (A), SW11.1
unnamed: D61.2 (A), D62.2 (A), SW17.1
unnamed: D63.2 (A), D64.2 (A), SW20.1
unnamed: D65.2 (A), D66.2 (A), SW6.1
unnamed: D67.2 (A), D68.2 (A), SW12.1
unnamed: D69.2 (A), D70.2 (A), SW18.1
unnamed: D71.2 (A), D72.2 (A), SW21.1
col0: SW2.2, SW8.2, SW14.2, U2.8 (5/PC6)
col1: SW3.2, SW9.2, SW15.2, U2.9 (6/PD7)
col2: SW1.2, SW4.2, SW10.2, SW16.2, U2.10 (7/PE6)
col3: SW5.2, SW11.2, SW17.2, SW20.2, U2.11 (8/PB4)
col4: SW6.2, SW12.2, SW18.2, SW21.2, U2.12 (9/PB5)
data: J1.3 (RING1), J2.3 (RING1), U2.2 (RX1/PD2)
gnd: D1.3 (VSS), D2.3 (VSS), D3.3 (VSS), D4.3 (VSS), D5.3 (VSS), D6.3 (VSS), D7.3 (VSS), D8.3 (VSS), D9.3 (VSS), D10.3 (VSS), D11.3 (VSS), D12.3 (VSS), D13.3 (VSS), D14.3 (VSS), D15.3 (VSS), D16.3 (VSS), D17.3 (VSS), D18.3 (VSS), D19.3 (VSS), D20.3 (VSS), D21.3 (VSS), D22.3 (VSS), D23.3 (VSS), D24.3 (VSS), D25.3 (VSS), D26.3 (VSS), D27.3 (VSS), D28.3 (VSS), D29.3 (VSS), D30.3 (VSS), D31.3 (VSS), D32.3 (VSS), D33.3 (VSS), D34.3 (VSS), D35.3 (VSS), D36.3 (VSS), J1.1 (SLEEVE), J1.2 (TIP), J2.1 (SLEEVE), J2.2 (TIP), OL1.4 (GND), OL2.4 (GND), RSW1.1, U2.3 (GND), U2.4 (GND), U2.23 (GND)
led: D1.4 (DIN), D19.4 (DIN), U2.1 (TX0/PD3)
reset: RSW1.2, U2.22 (RST)
row0: D37.1 (K), D38.1 (K), D43.1 (K), D44.1 (K), D49.1 (K), D50.1 (K), D57.1 (K), D58.1 (K), D65.1 (K), D66.1 (K), U2.7 (4/PD4)
row1: D39.1 (K), D40.1 (K), D45.1 (K), D46.1 (K), D51.1 (K), D52.1 (K), D59.1 (K), D60.1 (K), D67.1 (K), D68.1 (K), U2.20 (A3/PF4)
row2: D41.1 (K), D42.1 (K), D47.1 (K), D48.1 (K), D53.1 (K), D54.1 (K), D61.1 (K), D62.1 (K), D69.1 (K), D70.1 (K), U2.19 (A2/PF5)
row3: D55.1 (K), D56.1 (K), D63.1 (K), D64.1 (K), D71.1 (K), D72.1 (K), U2.18 (A1/PF6)
scl: OL1.2 (SCL), OL2.2 (SCL), U2.6 (3/PD0)
sda: OL1.1 (SDA), OL2.1 (SDA), U2.5 (2/PD1)
vcc: D1.1 (VDD), D2.1 (VDD), D3.1 (VDD), D4.1 (VDD), D5.1 (VDD), D6.1 (VDD), D7.1 (VDD), D8.1 (VDD), D9.1 (VDD), D10.1 (VDD), D11.1 (VDD), D12.1 (VDD), D13.1 (VDD), D14.1 (VDD), D15.1 (VDD), D16.1 (VDD), D17.1 (VDD), D18.1 (VDD), D19.1 (VDD), D20.1 (VDD), D21.1 (VDD), D22.1 (VDD), D23.1 (VDD), D24.1 (VDD), D25.1 (VDD), D26.1 (VDD), D27.1 (VDD), D28.1 (VDD), D29.1 (VDD), D30.1 (VDD), D31.1 (VDD), D32.1 (VDD), D33.1 (VDD), D34.1 (VDD), D35.1 (VDD), D36.1 (VDD), J1.4 (RING2), J2.4 (RING2), OL1.3 (VCC), OL2.3 (VCC), U2.21 (VCC)

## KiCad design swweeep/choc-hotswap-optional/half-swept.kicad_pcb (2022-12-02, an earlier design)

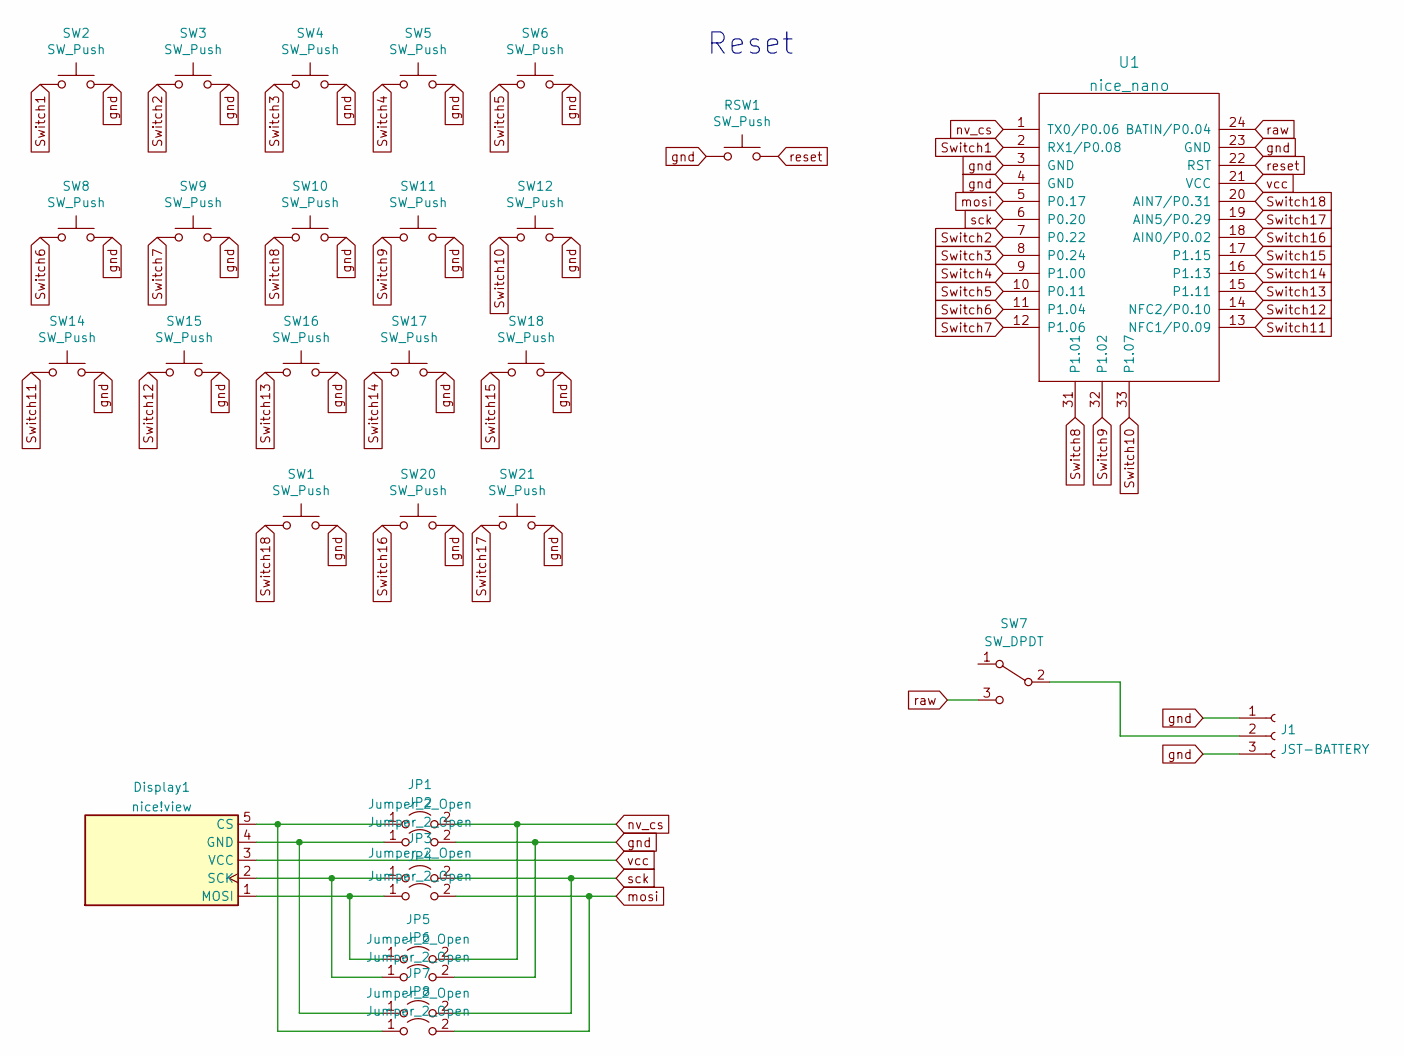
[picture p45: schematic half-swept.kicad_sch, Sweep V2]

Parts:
Display1: nice!view; nice_view
J1: JST-BATTERY; JST_PH_S3B-PH-K-keyboard; LCSC C157929
JP1, JP2, JP3, JP4, JP5, JP6, JP7, JP8: Jumper_2_Open; SolderJumper-2_P1.3mm_Open_TrianglePad1.0x1.5mm
RSW1: SW_Push; SW_Tactile_SPST_Angled_MJTP1117-no-mount
SW1, SW2, SW3, SW4, SW5, SW6, SW8, SW9, SW10, SW11, SW12, SW14, SW15, SW16, SW17, SW18, SW20, SW21: SW_Push; Kailh_socket_PG1350_optional_reversible_millmax
SW7: SW_DPDT; SW_CuK_OS102011MA1QN1_SPDT_Angled; LCSC C431540
U1: nice_nano

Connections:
unnamed: Display1.1 (MOSI), JP4.1 (A), JP5.1 (A)
unnamed: Display1.2 (SCK), JP3.1 (A), JP6.1 (A)
unnamed: Display1.4 (GND), JP2.1 (A), JP7.1 (A)
unnamed: Display1.5 (CS), JP1.1 (A), JP8.1 (A)
unnamed: J1.2, SW7.2 (B)
Switch1: SW2.1, U1.2 (RX1/P0.08)
Switch2: SW3.1, U1.7 (P0.22)
Switch3: SW4.1, U1.8 (P0.24)
Switch4: SW5.1, U1.9 (P1.00)
Switch5: SW6.1, U1.10 (P0.11)
Switch6: SW8.1, U1.11 (P1.04)
Switch7: SW9.1, U1.12 (P1.06)
Switch8: SW10.1, U1.31 (P1.01)
Switch9: SW11.1, U1.32 (P1.02)
Switch10: SW12.1, U1.33 (P1.07)
Switch11: SW14.1, U1.13 (NFC1/P0.09)
Switch12: SW15.1, U1.14 (NFC2/P0.10)
Switch13: SW16.1, U1.15 (P1.11)
Switch14: SW17.1, U1.16 (P1.13)
Switch15: SW18.1, U1.17 (P1.15)
Switch16: SW20.1, U1.18 (AIN0/P0.02)
Switch17: SW21.1, U1.19 (AIN5/P0.29)
Switch18: SW1.1, U1.20 (AIN7/P0.31)
gnd: J1.1, J1.3, JP2.2 (B), JP6.2 (B), RSW1.1, SW1.2, SW2.2, SW3.2, SW4.2, SW5.2, SW6.2, SW8.2, SW9.2, SW10.2, SW11.2, SW12.2, SW14.2, SW15.2, SW16.2, SW17.2, SW18.2, SW20.2, SW21.2, U1.3 (GND), U1.4 (GND), U1.23 (GND)
mosi: JP4.2 (B), JP8.2 (B), U1.5 (P0.17)
nv_cs: JP1.2 (B), JP5.2 (B), U1.1 (TX0/P0.06)
raw: SW7.3 (C), U1.24 (BATIN/P0.04)
reset: RSW1.2, U1.22 (RST)
sck: JP3.2 (B), JP7.2 (B), U1.6 (P0.20)
vcc: Display1.3 (VCC), U1.21 (VCC)

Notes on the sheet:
Reset

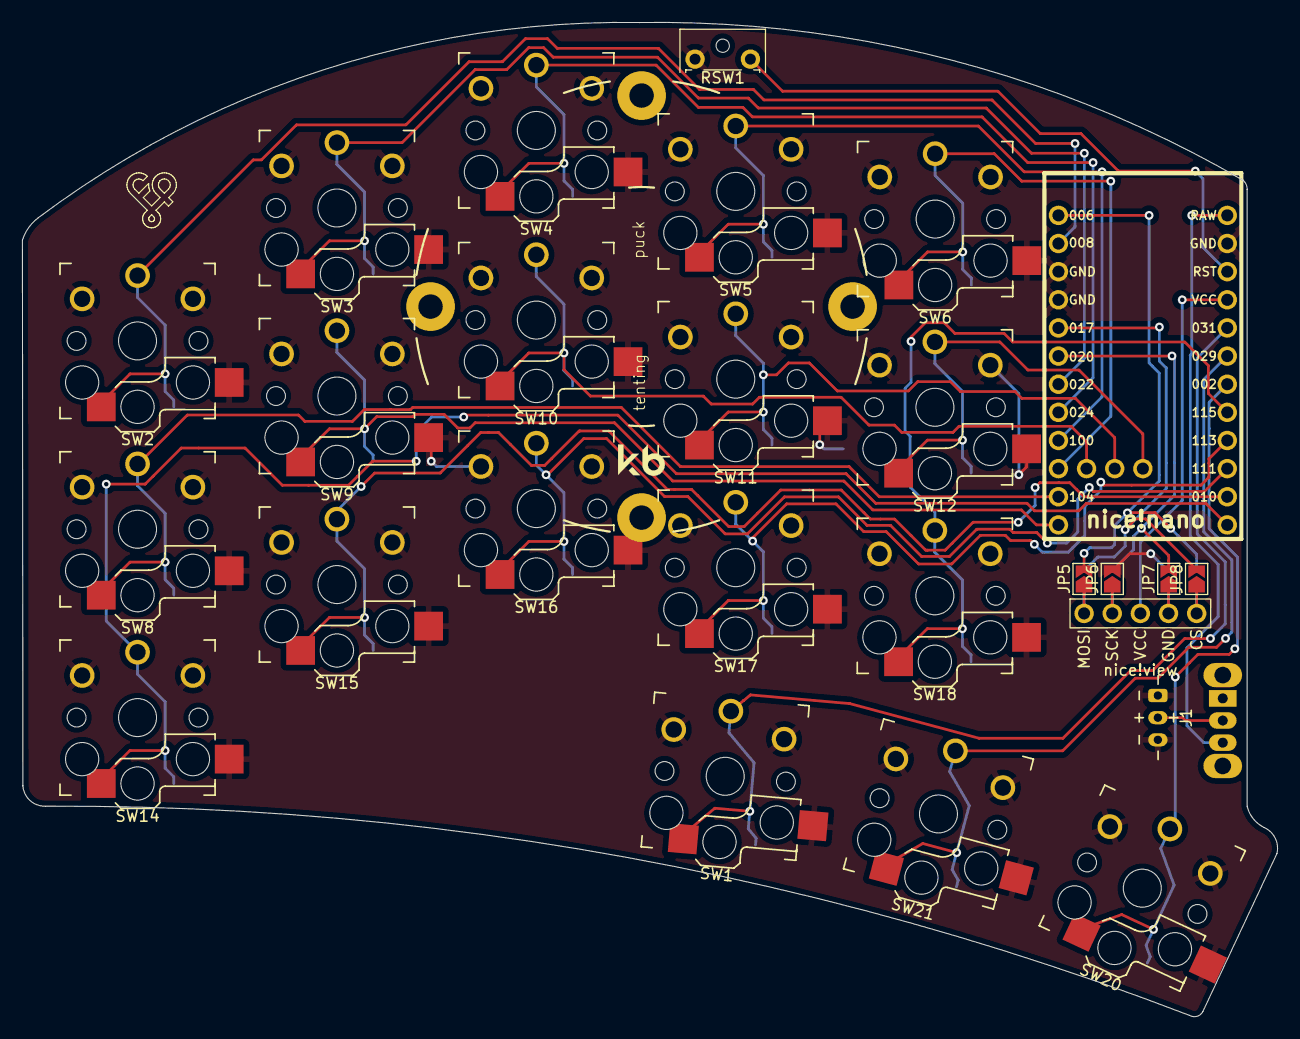
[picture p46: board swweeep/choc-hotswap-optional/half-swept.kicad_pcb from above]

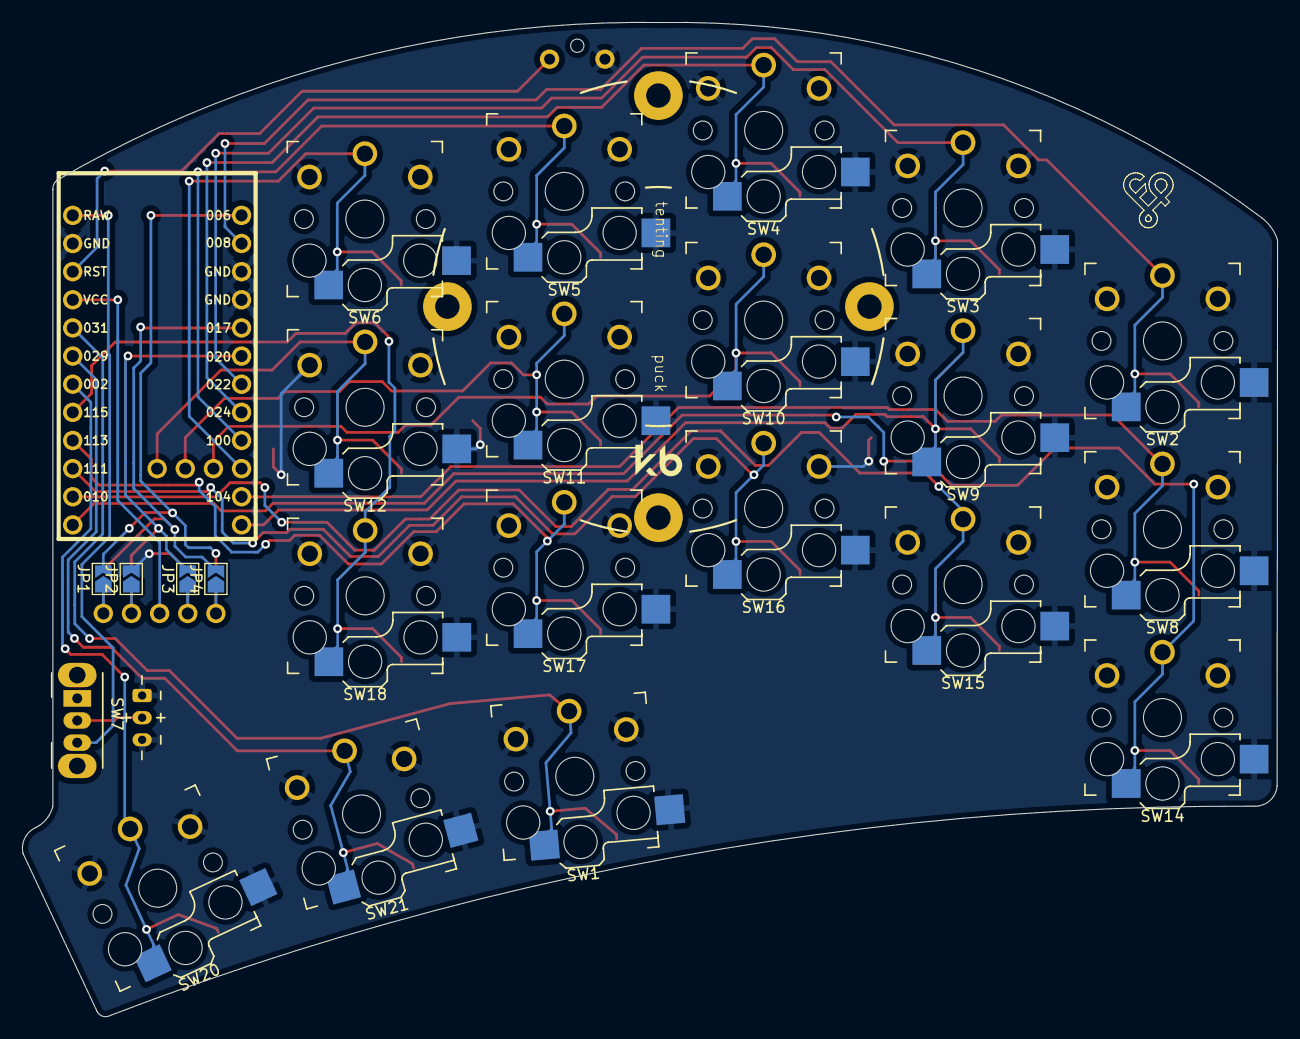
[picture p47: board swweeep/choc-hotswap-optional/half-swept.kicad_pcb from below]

Board: 2 copper layers, 113.3 x 89.7 mm, 31 parts (5 on the bottom side), 30 nets.

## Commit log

2022-03-12 initial commit, still needs to be tested
    [half-swept-B_Cu.gbr, half-swept-B_Mask.gbr, half-swept-B_Paste.gbr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]
2022-03-13 updated to include per key led support, oled support, 36 keys, still needs routing
    [half-swept.kicad_pcb, half-swept.kicad_sch]
2022-03-14 finished routing to complete elite-c, oled, per key led, and 36 key support
    [half-swept-B_Cu.gbr, half-swept-B_Mask.gbr, half-swept-B_Paste.gbr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]
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2022-04-20 made switch hole sizes a bit bigger to support mill max sockets
    [half-swept-B_Cu.gbr, half-swept-B_Mask.gbr, half-swept-B_Paste.gbr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]
2022-05-06 moved pcb into subdirectory for other versions
    [half-swept-B_Cu.gbr, half-swept-B_Mask.gbr, half-swept-B_Paste.gbr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]
2022-05-06 added choc hotswap version
    [half-swept-B_Cu.gbr, half-swept-B_Mask.gbr, half-swept-B_Paste.gbr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]
2022-05-06 added gateron ks27 switch support, in addition to the existing choc, on the same board
    [half-swept-B_Cu.gbr, half-swept-B_Mask.gbr, half-swept-B_Paste.gbr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]
2022-05-06 added reversible evq encoder version of the sweeeeep for lotemkw
    [half-swept-B_Cu.gbr, half-swept-B_Mask.gbr, half-swept-B_Paste.gbr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]
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2022-06-16 added new slight variant with rotated inner thumb, similar to corne. allows for greater than 1U keycaps
    [half-swept-B_Cu.gbr, half-swept-B_Mask.gbr, half-swept-B_Paste.gbr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]
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2022-10-21 added sweeeeep wireless with nice view support
    [half-swept-B_Cu.gbr, half-swept-B_Mask.gbr, half-swept-B_Paste.gbr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]
2022-10-21 updated wireless sweeeeeep to support mill-max as well
    [half-swept-B_Cu.gbr, half-swept-B_Mask.gbr, half-swept-B_Paste.gbr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]
2022-10-22 Change n!n pin assigmnets to match ZMK's nice_view_adapter
    [half-swept.kicad_pcb, half-swept.kicad_sch]
2022-10-22 regenerated gerbers based on gerrycave's pull request
    [half-swept-B_Cu.gbr, half-swept-B_Mask.gbr, half-swept-B_Paste.gbr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]
2022-10-22 made nice view reversible with jumpers, so it's only one footprint now instead of two offset
    [half-swept-B_Cu.gbr, half-swept-B_Mask.gbr, half-swept-B_Paste.gbr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]
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2022-10-24 renamed boards, updated readme, and moved directory structure to match
    [half-swept-B_Cu.gbr, half-swept-B_Mask.gbr, half-swept-B_Paste.gbr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]
2022-10-25 updated footprints to have user.drawings for easier svg exports
    [half-swept-brd.dxf, half-swept.kicad_pcb, half-swept.kicad_sch]
2022-10-25 first attempt at swweeep nice view case
    [swweeep-body-left.stl, swweeep-bot-left.stl]
2022-10-25 added a filet on the nice view cover on the top left edge, per patchesweaver's request
    [swweeep-body-left.stl]
2022-10-25 added open body version of the case
    [swweeep-body-covered-left.stl, swweeep-body-open-left.stl]
2022-10-25 added widecover version to fit battery on the side, along with step files
    [swweeep-body-covered-left.step, swweeep-body-covered-widecover-left.step, swweeep-body-covered-widecover-left.stl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]
2022-10-26 added tenting puck support for the bottom plates
    [swweeep-bot-left.step, swweeep-bot-left.stl, swweeep-bot-widecover-left.step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]
2022-10-27 added hole in bottom plate for reset switch
    [reset-switch.dxf, swweeep-bot-left.step, swweeep-bot-left.stl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]
2022-11-05 fixed height of case and cover for battery and nice view stock header height
    [swweeep-body-covered-left.step, swweeep-body-covered-left.stl, swweeep-body-covered-widecover-left.step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]
2022-11-05 nice view display hole was a bit too small, and on off switch hole wasn't aligned perfectly
    [swweeep-body-covered-left.step, swweeep-body-covered-left.stl, swweeep-body-covered-widecover-left.step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]
2022-11-06 added a 3mm high bottom plate to give more space for the battery and or jst connector
    [swweeep-bot-3mm-left.step, swweeep-bot-3mm-left.stl, swweeep-bot-widecover-3mm-left.step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]
2022-11-07 added step file for open body swweeep case
    [swweeep-body-open-left.step, swweeep-body-open-left.stl]
2022-11-10 fixed unconnected battery ground and updated readme with pics
    [half-swept-B_Cu.gbr, half-swept-B_Mask.gbr, half-swept-B_Paste.gbr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]
2022-11-12 feat: adding sweep case with no nice view hole
    [swweeep-body-covered-noNiceView-left v1.step, swweeep-body-covered-noNiceView-left v1.stl]
2022-11-16 added picture, readme, and tented bottom plates for swweeep case
    [swweeep-bot-10deg-battery-large.stl, swweeep-bot-10deg-battery-small.stl]
2022-11-16 moved the hole closer to the edge to allow space for the JST connector to go in
    [swweeep-bot-10deg-battery-large.stl]
2022-11-22 added one more bottom plate that's 5mm thick for very large batteries
    [swweeep-bot-5mm-left.step, swweeep-bot-5mm-left.stl]
2022-12-02 added 18650 holder for bottom plate
    [swweeep-bot-18deg-18650.stl]
2022-12-02 replaced on off switch, from MSK12C02 to OS102011MA1QN1
    [half-swept-B_Cu.gbr, half-swept-B_Mask.gbr, half-swept-B_Paste.gbr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]
2022-12-03 added on off switch extension for case
    [swweeep-on-off-extension-large.stl, swweeep-on-off-extension-medium.stl, swweeep-on-off-extension-small.stl]
2022-12-03 thinned out the lip a bit on the large on off extension stl
    [swweeep-on-off-extension-large.stl]
2022-12-20 adding step file for on off extension
    [swweeep-on-off-extension.step]
2023-06-28 feat(swweeep): Add a PCB Base and project files for use as a baseplate
    [swweeep-base-B_Cu.gbl, swweeep-base-B_Mask.gbs, swweeep-base-B_Paste.gbp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]
2023-07-21 first iteration of dweeeeep, which is a sweeeeep with diodes
    [bom.csv, designators.csv, half-swept.kicad_pcb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]
2023-10-06 added 18650 bottom plate with tenting puck holes for direct pcb mount
    [swweeep-bot-18deg-with-tenting-puck-18650.stl]
